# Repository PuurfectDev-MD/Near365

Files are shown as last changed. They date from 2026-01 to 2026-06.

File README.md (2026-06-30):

# Wacky and cute- *self claimed :)* Music Player 

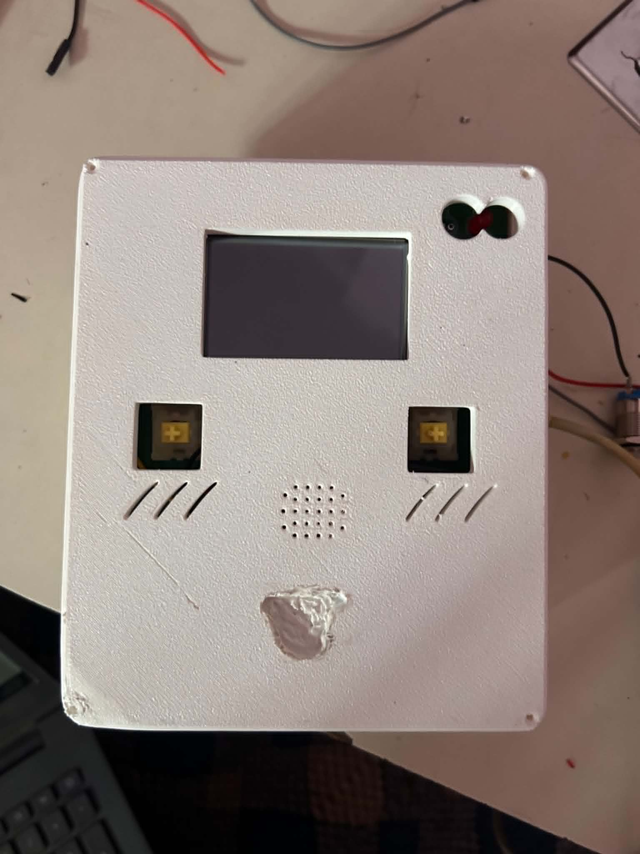
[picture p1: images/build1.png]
Build picture


**Music Player v1** is a interactive  media device (media form: music, voice recording, text, gifs and video possibly) powered by an ESP32-S3.I designed it as a personalized gift,to play unique music, affirmations,  every single day onpre-programmed schedule. v2 will have an APi endpoint to post voice recordings over the internet and other cool features. The device is a complete package for audio related projects and can be modified into other creative ideas like - (voice journal keeper, online music streaming and many more!)

---

## Features

* **Daily Present:** Automatically fetches unique content (music and text(affiramtions/notes)) from an SD card based on the current date.
* **High-quality Audio:** Uses I2S protocol with a MAX98357A DAC for clear, non-blocking WAV file playback.
* **Voice Recorder:** Record and save voice memos directly to the SD card for future playback ** Plans to stream it over the internet
* **Music Player:** Plays music playlists from the sd card
* **Peculiar Cute design** Cute 3d model case enclosure with a tounge sticking out 😛

---

##  Hardware Design

### Schematic
The system integrates an ESP32-S3 with I2S audio, SPI SD card communication, and I2C/SPI display interfacing.

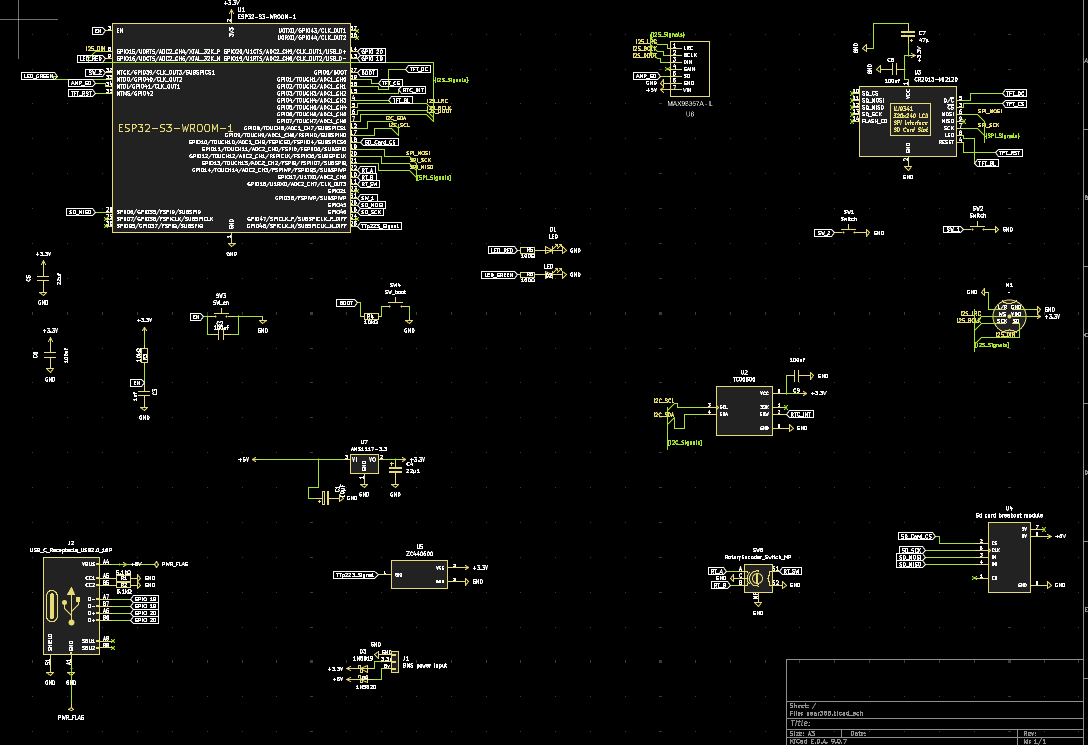
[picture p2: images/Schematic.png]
Schematic

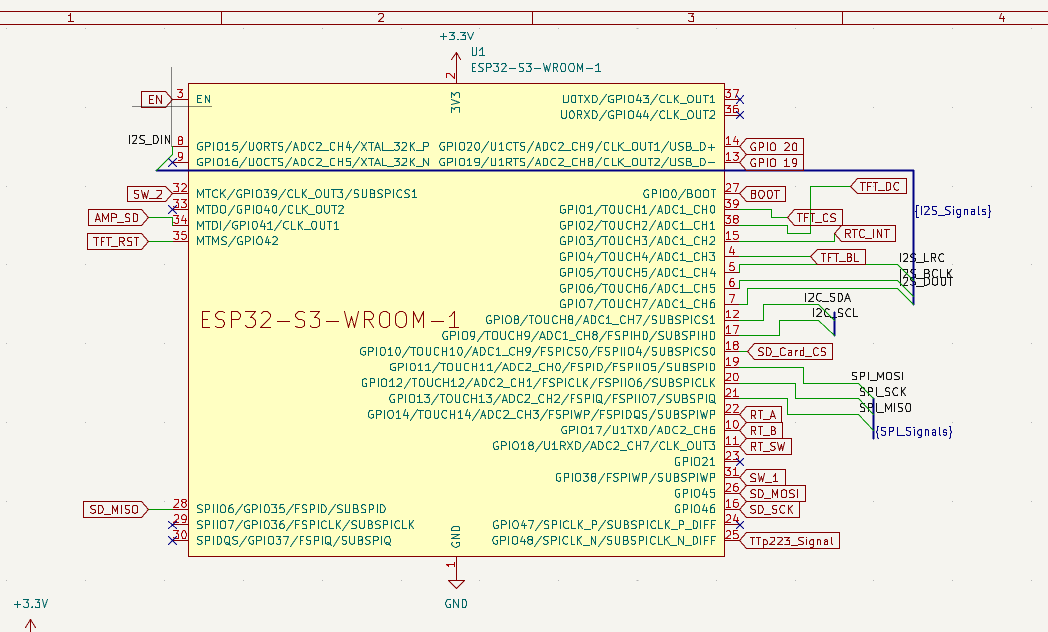
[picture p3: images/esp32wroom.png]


### PCB Design
A custom 2-layer PCB design from kicad.

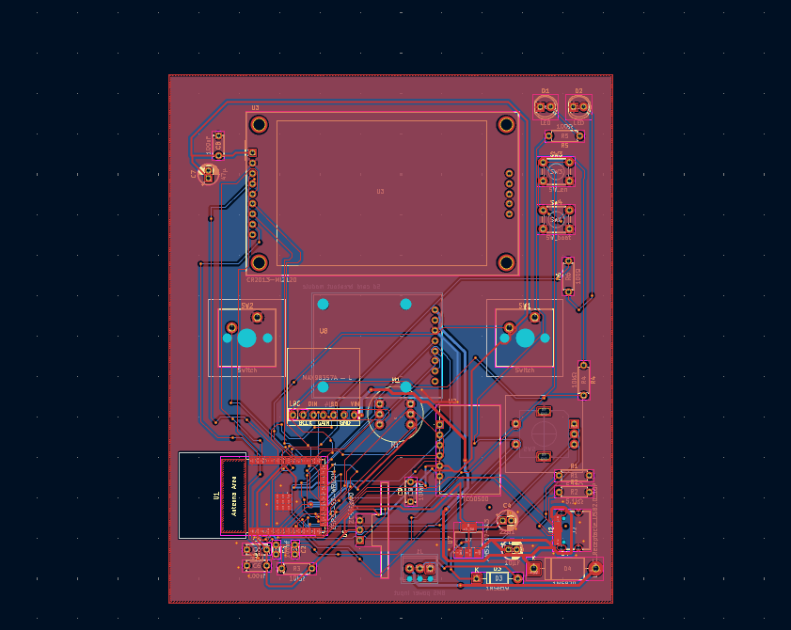
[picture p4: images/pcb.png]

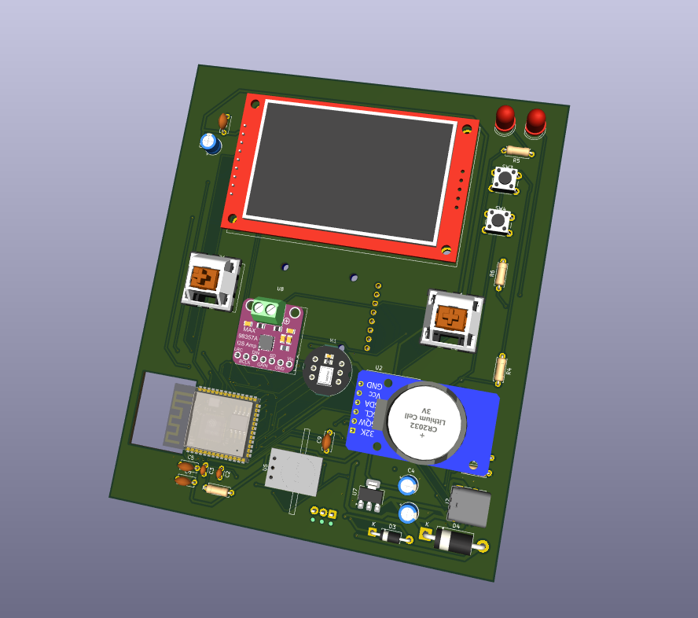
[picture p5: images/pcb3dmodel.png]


### Power Board
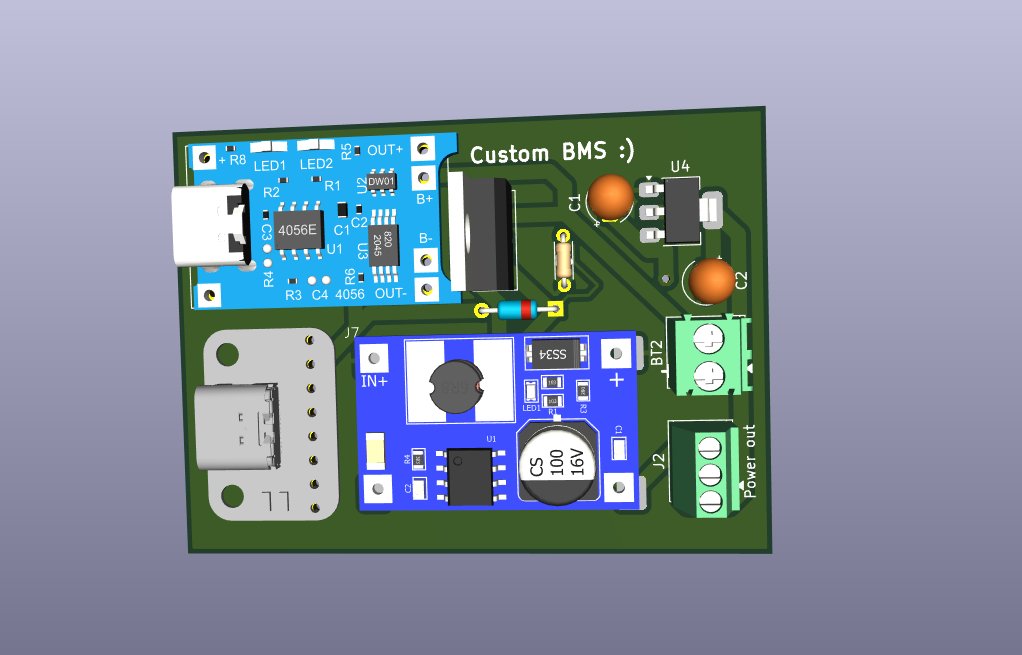
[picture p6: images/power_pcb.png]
Power PCB

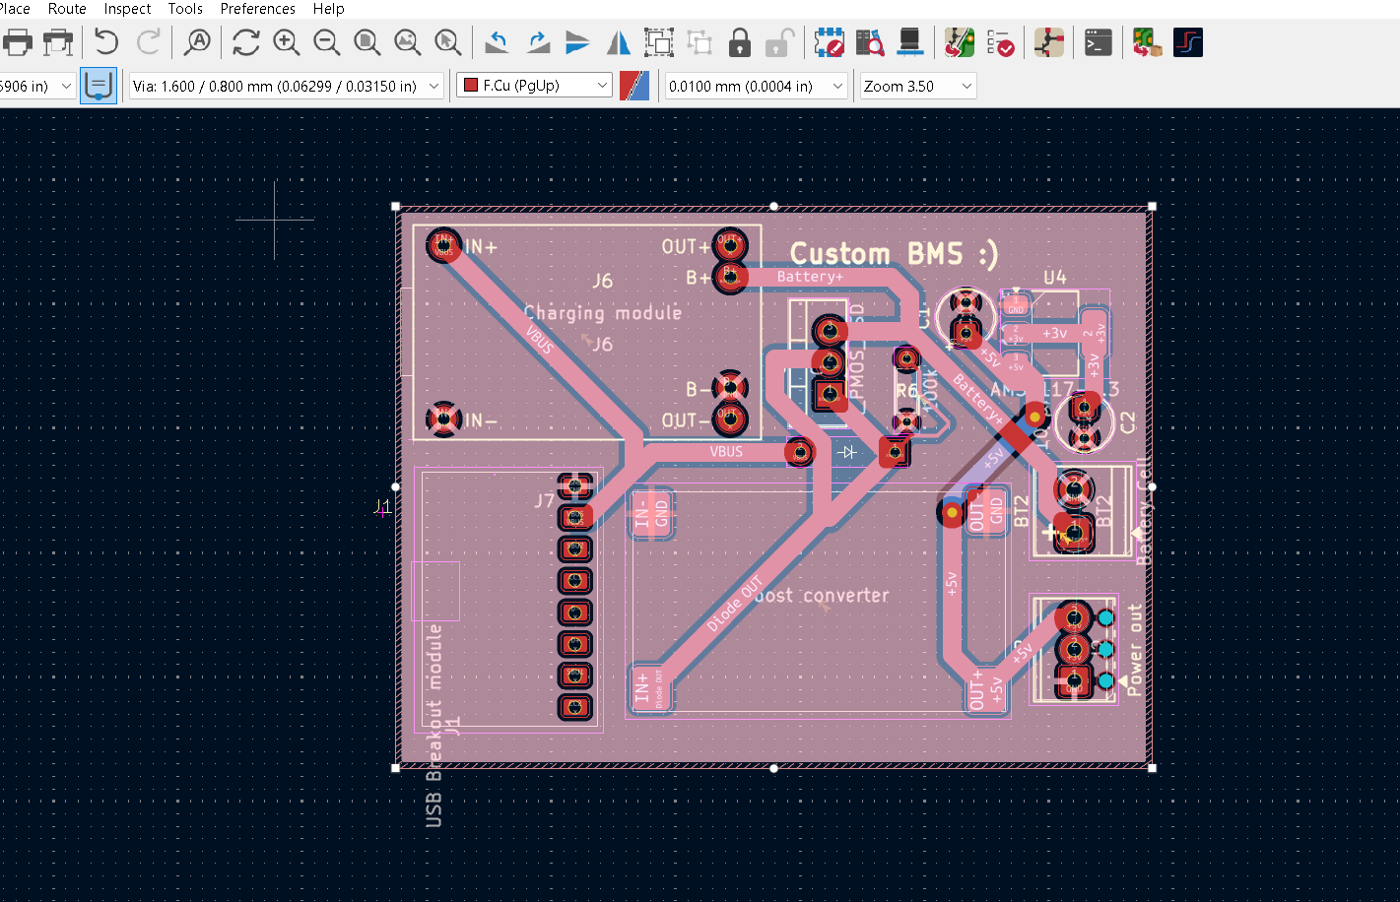
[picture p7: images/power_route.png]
Power traces

### 3D Model for Case
A custom 3d model case from fusion 360

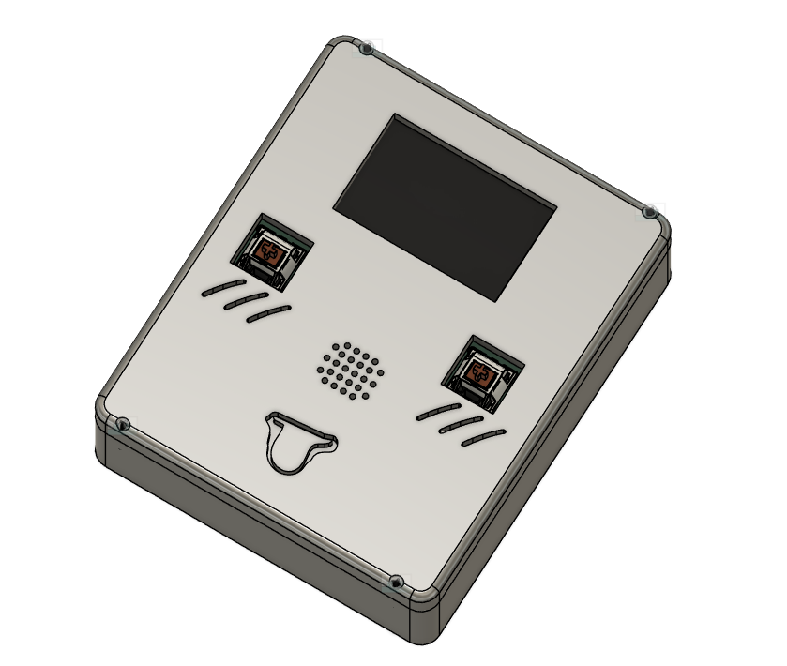
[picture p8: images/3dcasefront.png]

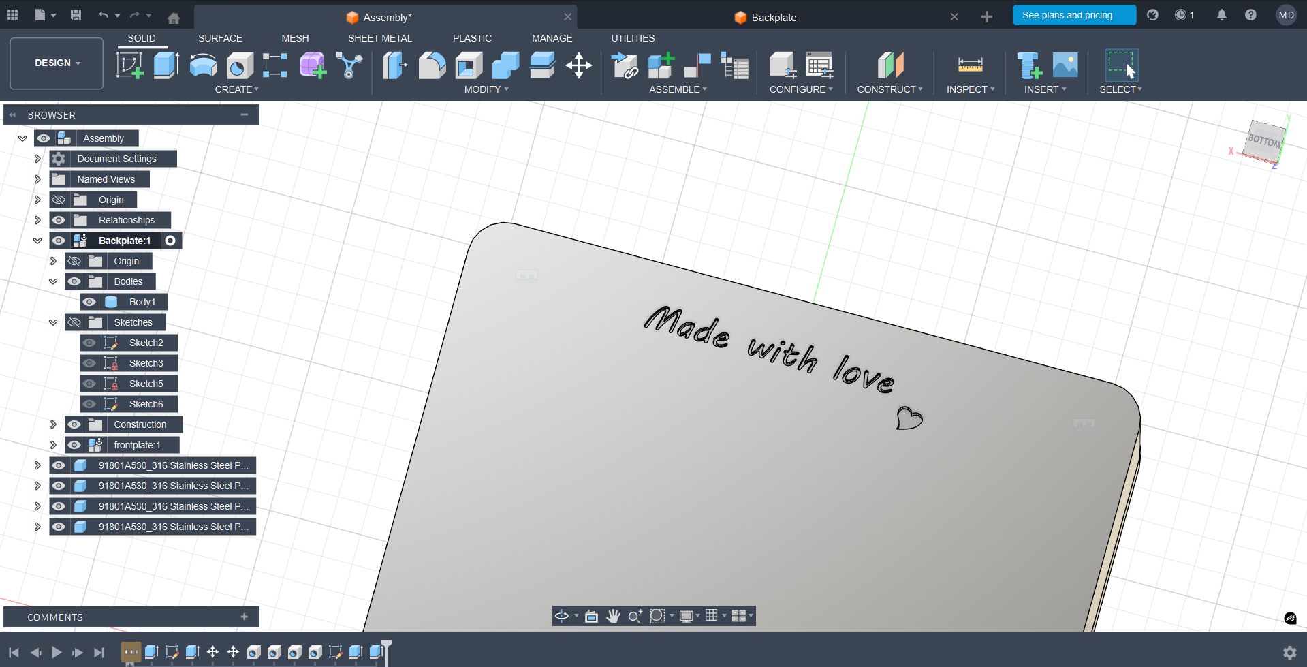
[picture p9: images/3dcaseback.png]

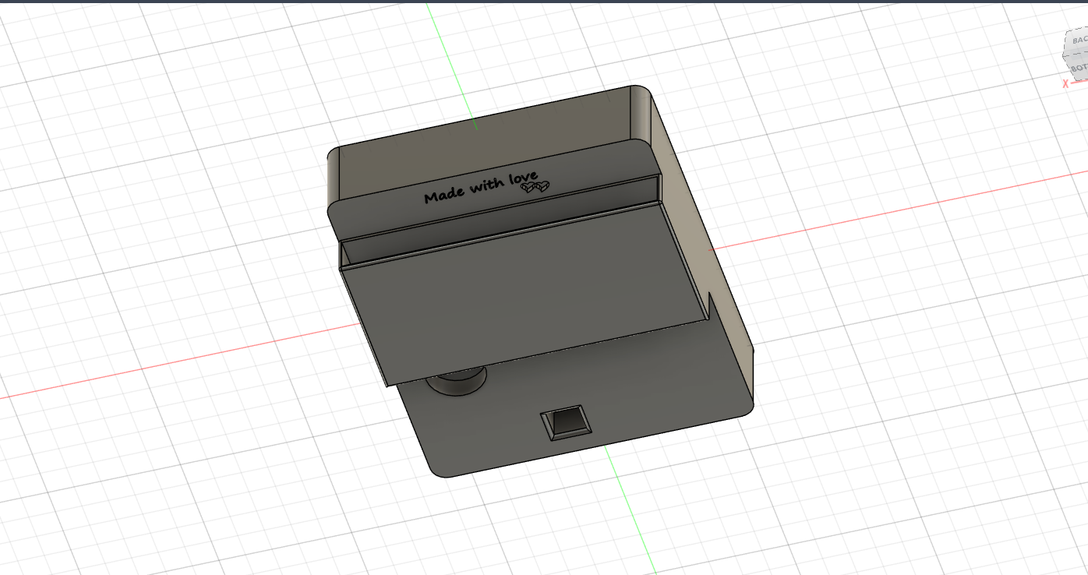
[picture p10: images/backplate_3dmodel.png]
3D Model Render

---
##  Bill of Materials (BOM)

| Component | Description | Quantity |
| :--- | :--- | :--- |
| **Microcontroller** | ESP32-S3 (WROOM-1-N16R8) | 1 |
| **Display** | 2.4" TFT LCD (ILI9341 Driver) | 1 |
| **Audio DAC/Amp** | MAX98357A I2S Class D Amplifier | 1 |
| **Speaker** | 3W 4-Ohm Internal Speaker | 1 |
| **Rotary Encoder** | EC11 Encoder with Push-Button Switch | 1 |
| **Touch Sensor** | TTP223 Capacitive Touch Module (Soft Power)  | 1 |
| **SD card module** | Adafruit Micro SD Card Breakout Board | 1 |
| **Microphone** | INMP441 I2S Digital Omnidirectional Mic | 1 |
| **RTC Module** | DS3231 High-Precision I2C RTC | 1 |
| **Storage Card** | 16GB Micro SD Card | 1 |
| **BMS Board** | Custom made battery management system | 1 |
> [!NOTE]
> This is just a summary of the BOM. The complete BOM can be found in [`/BOM details/project.csv`](BOM%20details/project.csv)
---

##  Project Structure

* `firmware/pages`: Contains the class logic for each UI state (`Daily`, `Music`, `Record`, `History`).
* `main.py`: The primary async loop and state machine handler.
* `setup.py`: Hardware initialization and pin mapping.
* `master.json`: The central database for the daily gift schedule.

## File Structure:

* `/3d Model`: Contains fusion and 3d printing files for the case.
* `/firmware`: Contains the code
* `Kicad`: Kicad files (both power and main board)
       * `Power_kicad`: Custom made bms system kicad project
       * `main_kicad`: main pcb kicad project
* `/images`: For images of README.md
* `/BOM details`: For BOM from Kicad and my cost compiled for the enitre project
          *`project.csv`: For cost compiled BOM
* `Gerber Files`: For JLCPCB or any other manufacturer
          * `production_main`: Gerber for the main pcb
          * `production_power`: Gerber for the BMS pcb

---

# Why build this?
I built it becasue I really wanted to get into making a custom esp32 chip board and happened to stumble upon a music player gift idea. And from there I spiralled into making the best version of my idea. It plays a different song and displays unique affiramtions from a predefined library to bringten up someones day. OFC my handcrafted playlist library is the biggest treasure :). You can build your own too! For yourself or for someone else. Good Luck >> After you complete it, share it with me from the info at https://manishd.is-a.dev/ .

# My build

### What Works Perfectly:
* **Playback:** Successfully fetches scheduled daily gifts/affirmations and plays audio
* **Network & Time Sync:** Connects to the internet to update and synchronize time data via API
* **Custom UI:** The custom LVGL-based TFT user interface turned out beautifully and performs well 

### Improvements that could better my build:
1. **The BMS Architecture:** Looking back, splitting the power/BMS circuit onto a separate board added unnecessary assembly complexity. For v2, the power management circuit will on a singl PCB.
2. **I2S Audio Recording:** While standalone microphone test scripts work flawlessly, fully integrating the voice-recording firmware into the main async package remains a work-in-progress becasue of some pin conflict
3. **Prototyping Materials Matter:** Using standard breadboard jumper wires and low-quality solder wire made internal routing extremely messy and prone to weak joints and gave me a veryvery hard time during building. This also made the final result messy and prone to breaking down/short ciruit.
4. **Hardware Casualty:** During the final hardware assembly stages, the TFT display took some physical damage which was just devestating. But it works kinda alright so fine i guess.

<details>
<summary><b> This is the tft after damage</b></summary>
<br />
<p align="center">
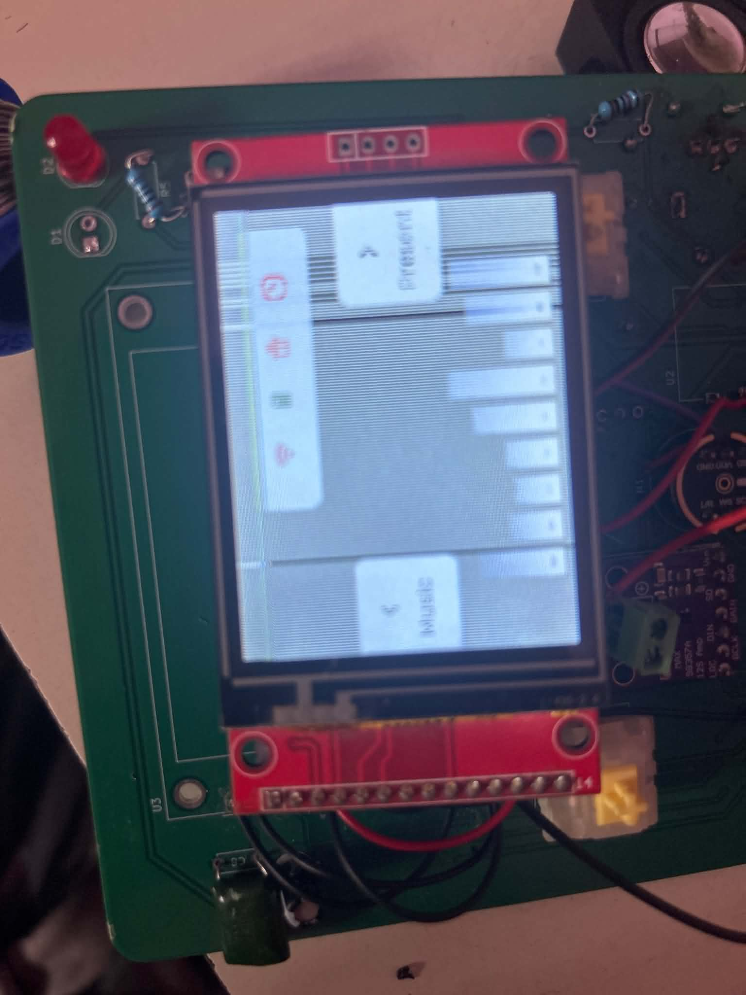
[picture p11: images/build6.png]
Internal Circuitry and Wiring
  
  <br />
  <sub>It works though so its fine guess.</sub>
</p>
</details>

---
> 💡 **Note:** This video was recorded during early testing. Some UI components shown in the gallery below are not visible in the clip. use the static images for final UI reference.

#### From the outside
<table width="100%">
  <tr>
    <td width="50%" align="center">
      Hardware Front View
      <br />
      <sub><b>Enclosure Assembly</b></sub>
    </td>
    <td width="50%" align="center">
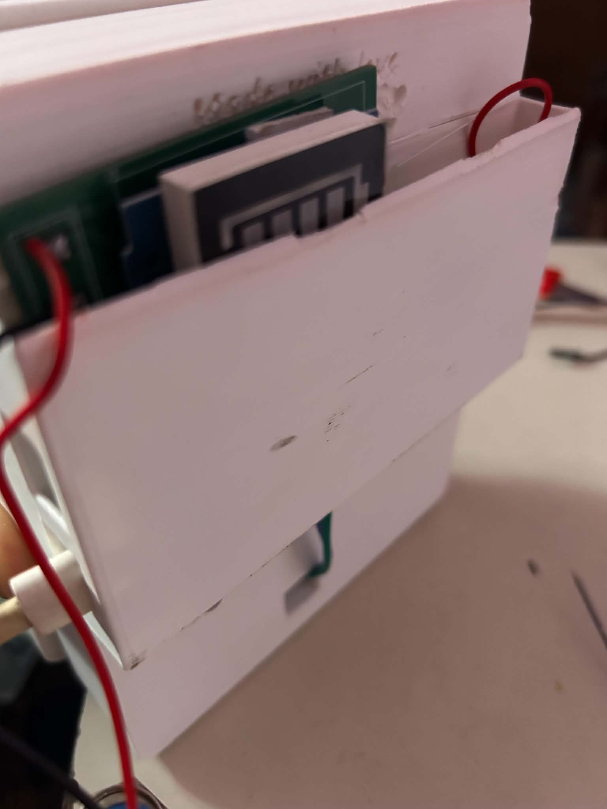
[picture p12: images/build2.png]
Hardware Angled View
      
      <br />
      <sub><b>Wacky Cute Tongue Profile 😛</b></sub>
    </td>
  </tr>
</table>

#### UI
<table width="100%">
  <tr>
    <td width="33%" align="center">
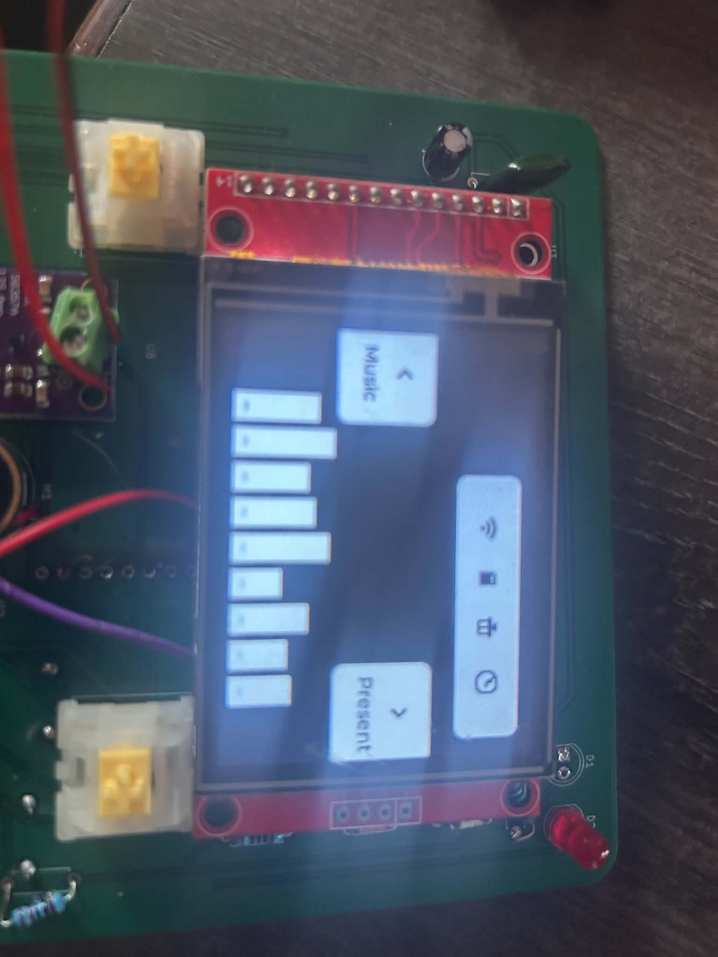
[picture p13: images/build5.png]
UI Screen Boot
      
      <br />
      <sub><b>Home</b></sub>
    </td>
    <td width="33%" align="center">
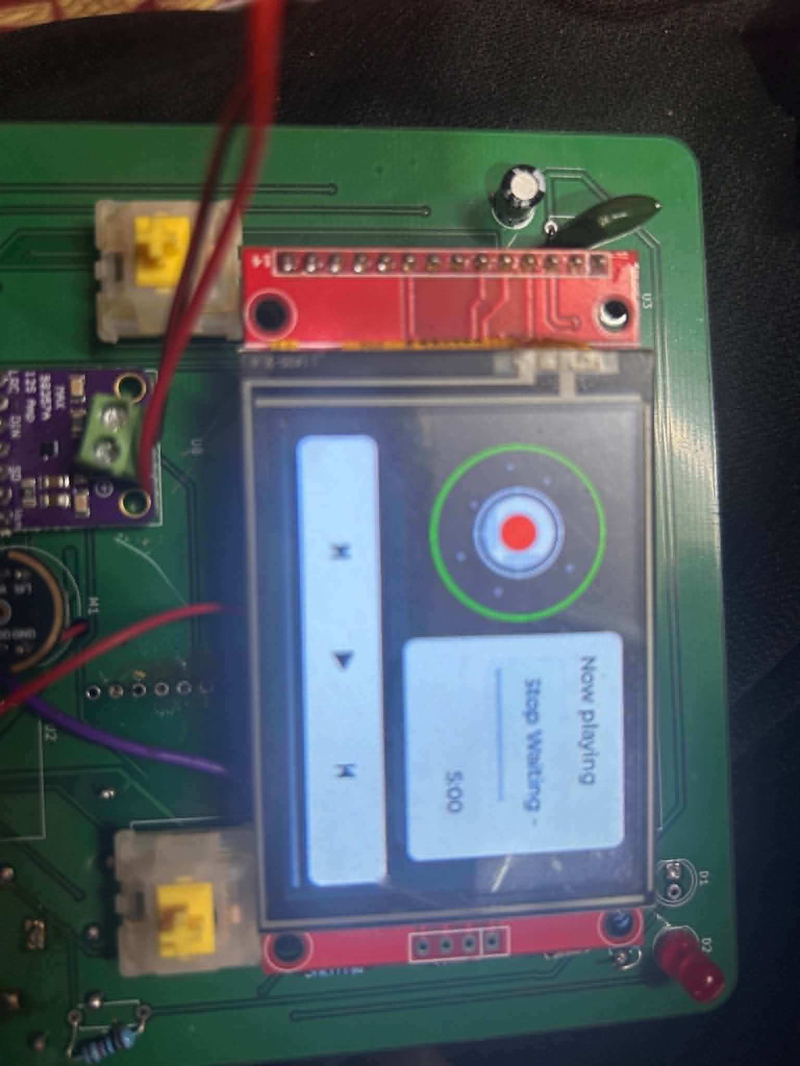
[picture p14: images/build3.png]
UI Menu Layout
      
      <br />
      <sub><b>Music Screen</b></sub>
    </td>
    <td width="33%" align="center">
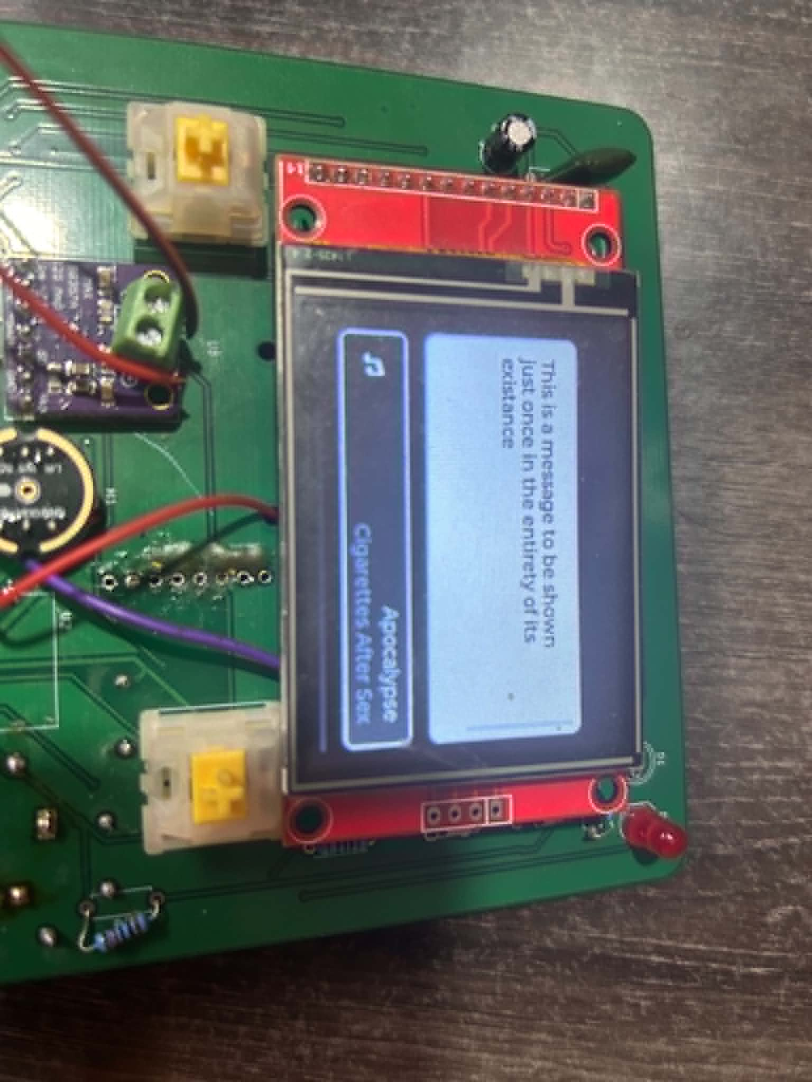
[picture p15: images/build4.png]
Assembled Face
      
      <br />
      <sub><b>Gift screen</b></sub>
    </td>
  </tr>
</table>

## AI USE:
I used AI heavily for the coding part. Around 40%-50%. Majority of the project is hardware based so AI use for the whole project is less than 25%. The things I used AI for - 

- Help with KICAD DRC issue
- Help with hole configuration on Fusion 360
- Troubleshooting design elements
- LVGL library and firmware setup (first time using it so thats why)
- LVGL library functions
- Acurate Encoder Input 

And a lot of debugging stuff.

*Created with love❤️.*

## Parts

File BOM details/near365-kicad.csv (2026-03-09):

Reference | Qty | Value | DNP | Exclude from BOM | Exclude from Board | Footprint | Datasheet
C1 | 1 | 10μF |  |  |  | Capacitor_THT:CP_Radial_D5.0mm_P2.00mm | ~
C2 | 1 | 100nf |  |  |  | Capacitor_THT:C_Disc_D3.0mm_W1.6mm_P2.50mm | ~
C3 | 1 | 1uf |  |  |  | Capacitor_THT:C_Disc_D3.0mm_W1.6mm_P2.50mm | ~
C4 | 1 | 22μ1 |  |  |  | Capacitor_THT:CP_Radial_D5.0mm_P2.00mm | ~
C5 | 1 | 22uf |  |  |  | Capacitor_THT:C_Disc_D5.0mm_W2.5mm_P5.00mm | ~
C6,C8,C9 | 3 | 100nf |  |  |  | Capacitor_THT:C_Disc_D5.0mm_W2.5mm_P5.00mm | ~
C7 | 1 | 47μ |  |  |  | Capacitor_THT:CP_Radial_D5.0mm_P2.00mm | ~
D1,D2 | 2 | LED |  |  |  | LED_THT:LED_D5.0mm | ~
D3 | 1 | 1N5819 |  |  |  | Diode_THT:D_DO-41_SOD81_P10.16mm_Horizontal | http://www.vishay.com/docs/88525/1n5817.pdf
D4 | 1 | 1N5820 |  |  |  | Diode_THT:D_DO-201AD_P15.24mm_Horizontal | http://www.vishay.com/docs/88526/1n5820.pdf
J1 | 1 | BMS power input |  |  |  | TerminalBlock_Phoenix:TerminalBlock_Phoenix_MPT-0,5-3-2.54_1x03_P2.54mm_Horizontal | ~
J2 | 1 | USB_C_Receptacle_USB2.0_16P |  |  |  | Connector_USB:USB_C_Receptacle_HRO_TYPE-C-31-M-12 | https://www.usb.org/sites/default/files/documents/usb_type-c.zip
M1 | 1 | ~ |  |  |  | INMP441_Microphone:INMP441_module
R1,R2 | 2 | 5.1kΩ |  |  |  | Resistor_THT:R_Axial_DIN0207_L6.3mm_D2.5mm_P7.62mm_Horizontal | ~
R3,R4 | 2 | 10kΩ |  |  |  | Resistor_THT:R_Axial_DIN0207_L6.3mm_D2.5mm_P7.62mm_Horizontal | ~
R5,R6 | 2 | 100Ω |  |  |  | Resistor_THT:R_Axial_DIN0207_L6.3mm_D2.5mm_P7.62mm_Horizontal | ~
SW1,SW2 | 2 | Switch |  |  |  | ScottoKeebs_MX:MX_PCB_1.00u | ~
SW3 | 1 | SW_en |  |  |  | Button_Switch_THT:SW_PUSH_6mm | ~
SW4 | 1 | SW_boot |  |  |  | Button_Switch_THT:SW_PUSH_6mm | ~
SW5 | 1 | RotaryEncoder_Switch_MP |  |  |  | ScottoKeebs_Scotto:Encoder_EC11_MX | ~
U1 | 1 | ESP32-S3-WROOM-1 |  |  |  | PCM_Espressif:ESP32-S3-WROOM-1 | https://www.espressif.com/sites/default/files/documentation/esp32-s3-wroom-1_wroom-1u_datasheet_en.pdf
U2 | 1 | TC00500 |  |  |  | Real_TimeClk:MODULE_TC00500
U3 | 1 | CR2013-MI2120 |  |  |  | Display:CR2013-MI2120 | http://pan.baidu.com/s/11Y990
U4 | 1 | Sd card breakout module |  |  |  | Adafruit Sd breakout:MODULE_254
U5 | 1 | ZC440600 |  |  |  | TTP223:MODULE_ZC440600
U7 | 1 | AMS1117-3.3 |  |  |  | Package_TO_SOT_SMD:SOT-223-3_TabPin2 | http://www.advanced-monolithic.com/pdf/ds1117.pdf
U8 | 1 | MAX98357A - L |  |  |  | MAX98357A_custom:MAX98357A_Adafruit_Breakout | https://www.adafruit.com/product/3006

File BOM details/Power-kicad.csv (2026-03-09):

Reference | Qty | Value | DNP | Exclude from BOM | Exclude from Board | Footprint | Datasheet
BT2 | 1 | Battery_Cell |  |  |  | TerminalBlock_Phoenix:TerminalBlock_Phoenix_PT-1,5-2-3.5-H_1x02_P3.50mm_Horizontal | ~
C1,C2 | 2 | 10 µF |  |  |  | Capacitor_THT:CP_Radial_Tantal_D4.5mm_P2.50mm | ~
D2 | 1 | ~ |  |  |  | ScottoKeebs_Components:Diode_DO-35
J1 | 1 | USB Breakout module |  |  |  | USB Breakout board:Usb_breakout board | ~
J2 | 1 | Power out |  |  |  | TerminalBlock_Phoenix:TerminalBlock_Phoenix_MPT-0,5-3-2.54_1x03_P2.54mm_Horizontal | ~
J6 | 1 | Charging module |  |  |  | Charging module:TP4056-Module | ~
J7 | 1 | Boost converter |  |  |  | Boost_converter_module:Boost_converter_3A | ~
Q2 | 1 | Q_PMOS_GSD |  |  |  | Package_TO_SOT_THT:TO-220-3_Vertical | ~
R6 | 1 | 100k |  |  |  | Resistor_THT:R_Axial_DIN0204_L3.6mm_D1.6mm_P5.08mm_Horizontal | ~
U4 | 1 | AMS1117-3.3 |  |  |  | Package_TO_SOT_SMD:SOT-223-3_TabPin2 | http://www.advanced-monolithic.com/pdf/ds1117.pdf

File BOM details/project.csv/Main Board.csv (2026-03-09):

Reference | Qty | Value | Footprint | Price | Datasheet
C1 | 1 | 10μF | Capacitor_THT:CP_Radial_D5.0mm_P2.00mm | $0.35 | ~
C2 | 1 | 100nf | Capacitor_THT:C_Disc_D3.0mm_W1.6mm_P2.50mm | $0.35 | ~
C3 | 1 | 1uf | Capacitor_THT:C_Disc_D3.0mm_W1.6mm_P2.50mm | $0.35 | ~
C4 | 1 | 22μ1 | Capacitor_THT:CP_Radial_D5.0mm_P2.00mm | $0.35 | ~
C5 | 1 | 22uf | Capacitor_THT:C_Disc_D5.0mm_W2.5mm_P5.00mm | $0.35 | ~
C6,C8,C9 | 3 | 100nf | Capacitor_THT:C_Disc_D5.0mm_W2.5mm_P5.00mm | $0.35 | ~
C7 | 1 | 47μ | Capacitor_THT:CP_Radial_D5.0mm_P2.00mm | $0.35 | ~
%s12.00 | 2 | LED | LED_THT:LED_D5.0mm | $0.20 | ~
D3 | 1 | 1N5819 | Diode_THT:D_DO-41_SOD81_P10.16mm_Horizontal | $1 | http://www.vishay.com/docs/88525/1n5817.pdf
D4 | 1 | 1N5820 | Diode_THT:D_DO-201AD_P15.24mm_Horizontal | $2 | http://www.vishay.com/docs/88526/1n5820.pdf
J1 | 1 | BMS power input | TerminalBlock_Phoenix:TerminalBlock_Phoenix_MPT-0,5-3-2.54_1x03_P2.54mm_Horizontal | $1 | ~
J2 | 1 | USB_C_Receptacle_USB2.0_16P | Connector_USB:USB_C_Receptacle_HRO_TYPE-C-31-M-12 | $3 | https://www.usb.org/sites/default/files/documents/usb_type-c.zip
M1 | 1 | ~ | INMP441_Microphone:INMP441_module | $3
%s12.00 | 2 | 5.1kΩ | Resistor_THT:R_Axial_DIN0207_L6.3mm_D2.5mm_P7.62mm_Horizontal | $0.10 | ~
%s34.00 | 2 | 10kΩ | Resistor_THT:R_Axial_DIN0207_L6.3mm_D2.5mm_P7.62mm_Horizontal | $0.10 | ~
%s56.00 | 2 | 100Ω | Resistor_THT:R_Axial_DIN0207_L6.3mm_D2.5mm_P7.62mm_Horizontal | $0.10 | ~
SW1,SW2 | 2 | Switch | ScottoKeebs_MX:MX_PCB_1.00u | $2 | ~
SW3 | 1 | SW_en | Button_Switch_THT:SW_PUSH_6mm | $0.50 | ~
SW4 | 1 | SW_boot | Button_Switch_THT:SW_PUSH_6mm | $0.50 | ~
SW5 | 1 | RotaryEncoder_Switch_MP | ScottoKeebs_Scotto:Encoder_EC11_MX | $3 | ~
U1 | 1 | ESP32-S3-WROOM-1 | PCM_Espressif:ESP32-S3-WROOM-1 | $4 | https://www.espressif.com/sites/default/files/documentation/esp32-s3-wroom-1_wroom-1u_datasheet_en.pdf
U2 | 1 | TC00500 | Real_TimeClk:MODULE_TC00500 | $2
U3 | 1 | TFT display | Display:CR2013-MI2120 | $8.23 | http://pan.baidu.com/s/11Y990
U4 | 1 | Sd card breakout module | Adafruit Sd breakout:MODULE_254 | $10
U5 | 1 | ZC440600 | TTP223:MODULE_ZC440600 | $0.50
U7 | 1 | AMS1117-3.3 | Package_TO_SOT_SMD:SOT-223-3_TabPin2 | $1 | http://www.advanced-monolithic.com/pdf/ds1117.pdf
U8 | 1 | MAX98357A - L | MAX98357A_custom:MAX98357A_Adafruit_Breakout | $2 | https://www.adafruit.com/product/3006
 | 1 | SD Card- 8GB |  | $5
 |  |  | Total: | $50.68

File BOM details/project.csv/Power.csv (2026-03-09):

Reference | Qty | Value | Price | Footprint
BT2 | 1 | Battery_Cell | $6 | TerminalBlock_Phoenix:TerminalBlock_Phoenix_PT-1,5-2-3.5-H_1x02_P3.50mm_Horizontal
C1,C2 | 2 | 10 µF | $0.20 | Capacitor_THT:CP_Radial_Tantal_D4.5mm_P2.50mm
D2 | 1 | ~ | $0.50 | ScottoKeebs_Components:Diode_DO-35
J1 | 1 | USB Breakout module | $1 | USB Breakout board:Usb_breakout board
J2 | 1 | Power out | $1.26 | TerminalBlock_Phoenix:TerminalBlock_Phoenix_MPT-0,5-3-2.54_1x03_P2.54mm_Horizontal
J6 | 1 | Charging module | $1.50 | Charging module:TP4056-Module
J7 | 1 | Boost converter | $3.50 | Boost_converter_module:Boost_converter_3A
Q2 | 1 | Q_PMOS_GSD | $1 | Package_TO_SOT_THT:TO-220-3_Vertical
R6 | 1 | 100k | $0.10 | Resistor_THT:R_Axial_DIN0204_L3.6mm_D1.6mm_P5.08mm_Horizontal
U4 | 1 | AMS1117-3.3 | $1 | Package_TO_SOT_SMD:SOT-223-3_TabPin2
 |  | Total: | $16

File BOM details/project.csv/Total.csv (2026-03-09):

Item | Price | Shipping | Total
Main Board | $50.68 | $10
Power Board | $16
Soldering Flux paste | $2.50
M2 * 16mm Screws | $1.62
PCB Cost for Main Board | $10
PCB Cost for Power Board | $2 | $15
3d printing costs for the case | $25 | $15
 | Total: $110 | $40
 | Final Total: | $150

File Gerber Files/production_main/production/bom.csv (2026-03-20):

Designator | Footprint | Quantity | Value | LCSC Part #
C1 | CP_Radial_D5.0mm_P2.00mm | 1 | 10μF
C2 | C_Disc_D3.0mm_W1.6mm_P2.50mm | 1 | 100nf
C3 | C_Disc_D3.0mm_W1.6mm_P2.50mm | 1 | 1uf
C4 | CP_Radial_D5.0mm_P2.00mm | 1 | 22μ1
C5 | C_Disc_D5.0mm_W2.5mm_P5.00mm | 1 | 22uf
C6, C8, C9 | C_Disc_D5.0mm_W2.5mm_P5.00mm | 3 | 100nf
C7 | CP_Radial_D5.0mm_P2.00mm | 1 | 47μ
D1, D2 | LED_D5.0mm | 2 | LED
D3 | D_DO-41_SOD81_P10.16mm_Horizontal | 1 | 1N5819
D4 | D_DO-201AD_P15.24mm_Horizontal | 1 | 1N5820
J1 | TerminalBlock_Phoenix_MPT-0,5-3-2.54_1x03_P2.54mm_Horizontal | 1 | BMS power input
J2 | USB_C_Receptacle_HRO_TYPE-C-31-M-12 | 1 | USB_C_Receptacle_USB2.0_16P
M1 | INMP441_module | 1 | ~
R1, R2 | R_Axial_DIN0207_L6.3mm_D2.5mm_P7.62mm_Horizontal | 2 | 5.1kΩ
R3, R4, R7, R8, R9 | R_Axial_DIN0207_L6.3mm_D2.5mm_P7.62mm_Horizontal | 5 | 10kΩ
R5, R6 | R_Axial_DIN0207_L6.3mm_D2.5mm_P7.62mm_Horizontal | 2 | 100Ω
SW1, SW2 | MX_PCB_1.00u | 2 | Switch
SW3 | SW_PUSH_6mm | 1 | SW_en
SW4 | SW_PUSH_6mm | 1 | SW_boot
SW5 | Encoder_EC11_MX | 1 | RotaryEncoder_Switch_MP
U1 | ESP32-S3-WROOM-1 | 1 | ESP32-S3-WROOM-1
U2 | MODULE_TC00500 | 1 | TC00500
U3 | CR2013-MI2120 | 1 | CR2013-MI2120
U4 | MODULE_254 | 1 | Sd card breakout module
U5 | MODULE_ZC440600 | 1 | ZC440600
U7 | SOT-223-3_TabPin2 | 1 | AMS1117-3.3
U8 | MAX98357A_Adafruit_Breakout | 1 | MAX98357A - L

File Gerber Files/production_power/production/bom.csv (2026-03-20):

Designator | Footprint | Quantity | Value | LCSC Part #
BT2 | TerminalBlock_Phoenix_PT-1,5-2-3.5-H_1x02_P3.50mm_Horizontal | 1 | Battery_Cell
C1, C2 | CP_Radial_Tantal_D4.5mm_P2.50mm | 2 | 10 µF
D2 | Diode_DO-35 | 1 | ~
J1 | Usb_breakout board | 1 | USB Breakout module
J2 | TerminalBlock_Phoenix_MPT-0,5-3-2.54_1x03_P2.54mm_Horizontal | 1 | Power out
J3 | charge_display | 1 | Charge display
J6 | TP4056-Module | 1 | Charging module
J7 | Boost_converter_3A | 1 | Boost converter
Q2 | TO-220-3_Vertical | 1 | Q_PMOS_GSD
R6 | R_Axial_DIN0204_L3.6mm_D1.6mm_P5.08mm_Horizontal | 1 | 100k
SW1 | Switch_pads | 1 | SW_Push
U4 | SOT-223-3_TabPin2 | 1 | AMS1117-3.3

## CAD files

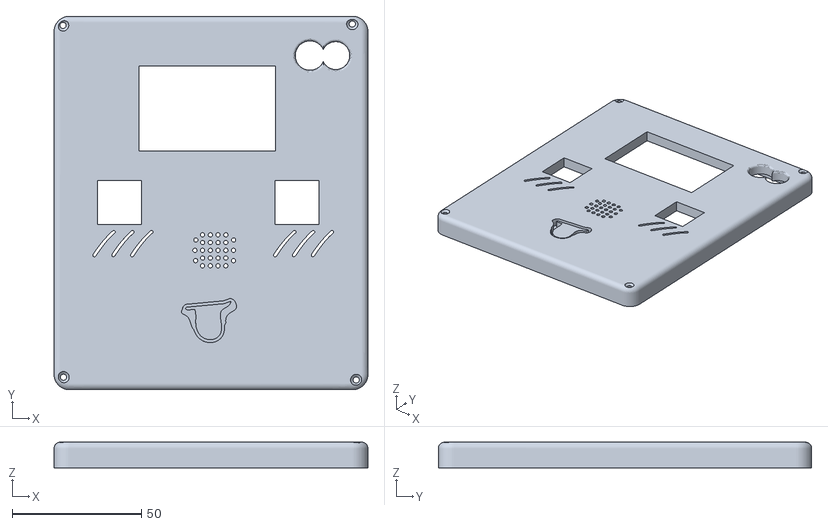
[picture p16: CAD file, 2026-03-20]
3d Model/fusion360/.stl for printing/frontplate.stl
121.6 x 144.7 x 10.0

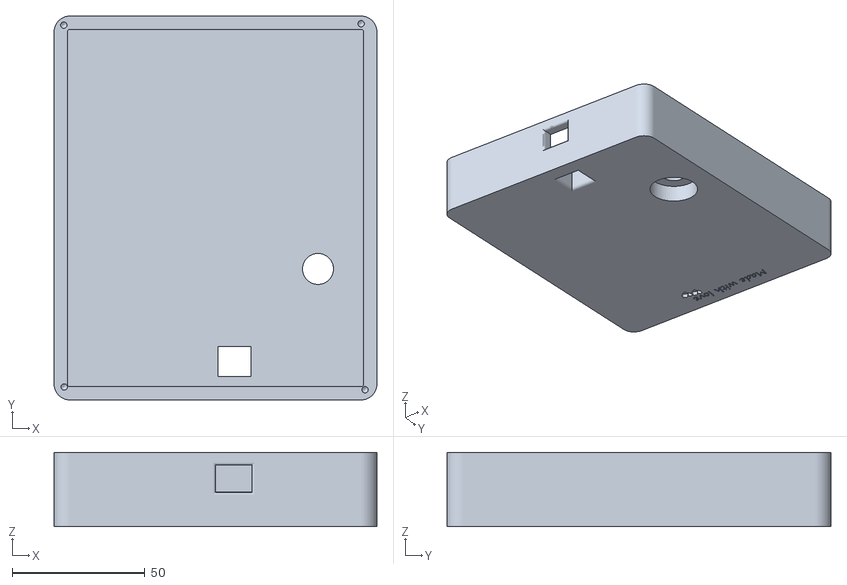
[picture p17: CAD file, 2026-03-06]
3d Model/fusion360/.stl for printing/backplate.stl
121.6 x 144.7 x 28.0

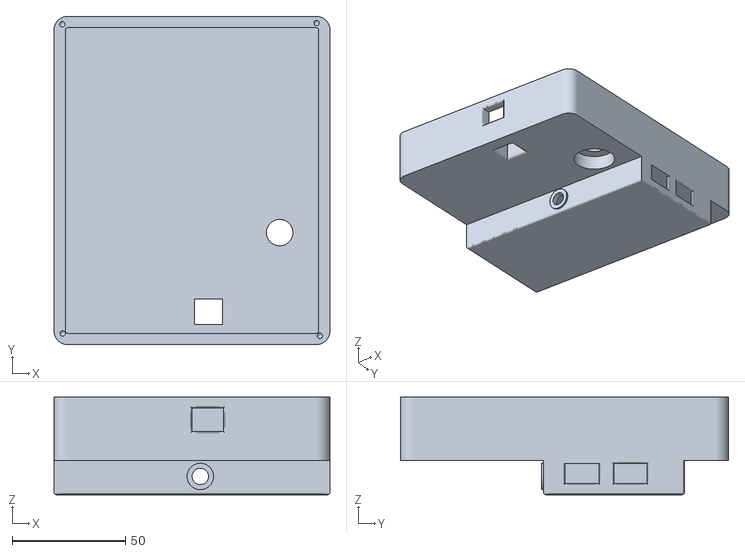
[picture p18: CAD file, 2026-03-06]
3d Model/fusion360/.stl for printing/backplate_redesign.stl
121.6 x 144.7 x 43.0

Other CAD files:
3d Model/fusion360/frontplate.f3z

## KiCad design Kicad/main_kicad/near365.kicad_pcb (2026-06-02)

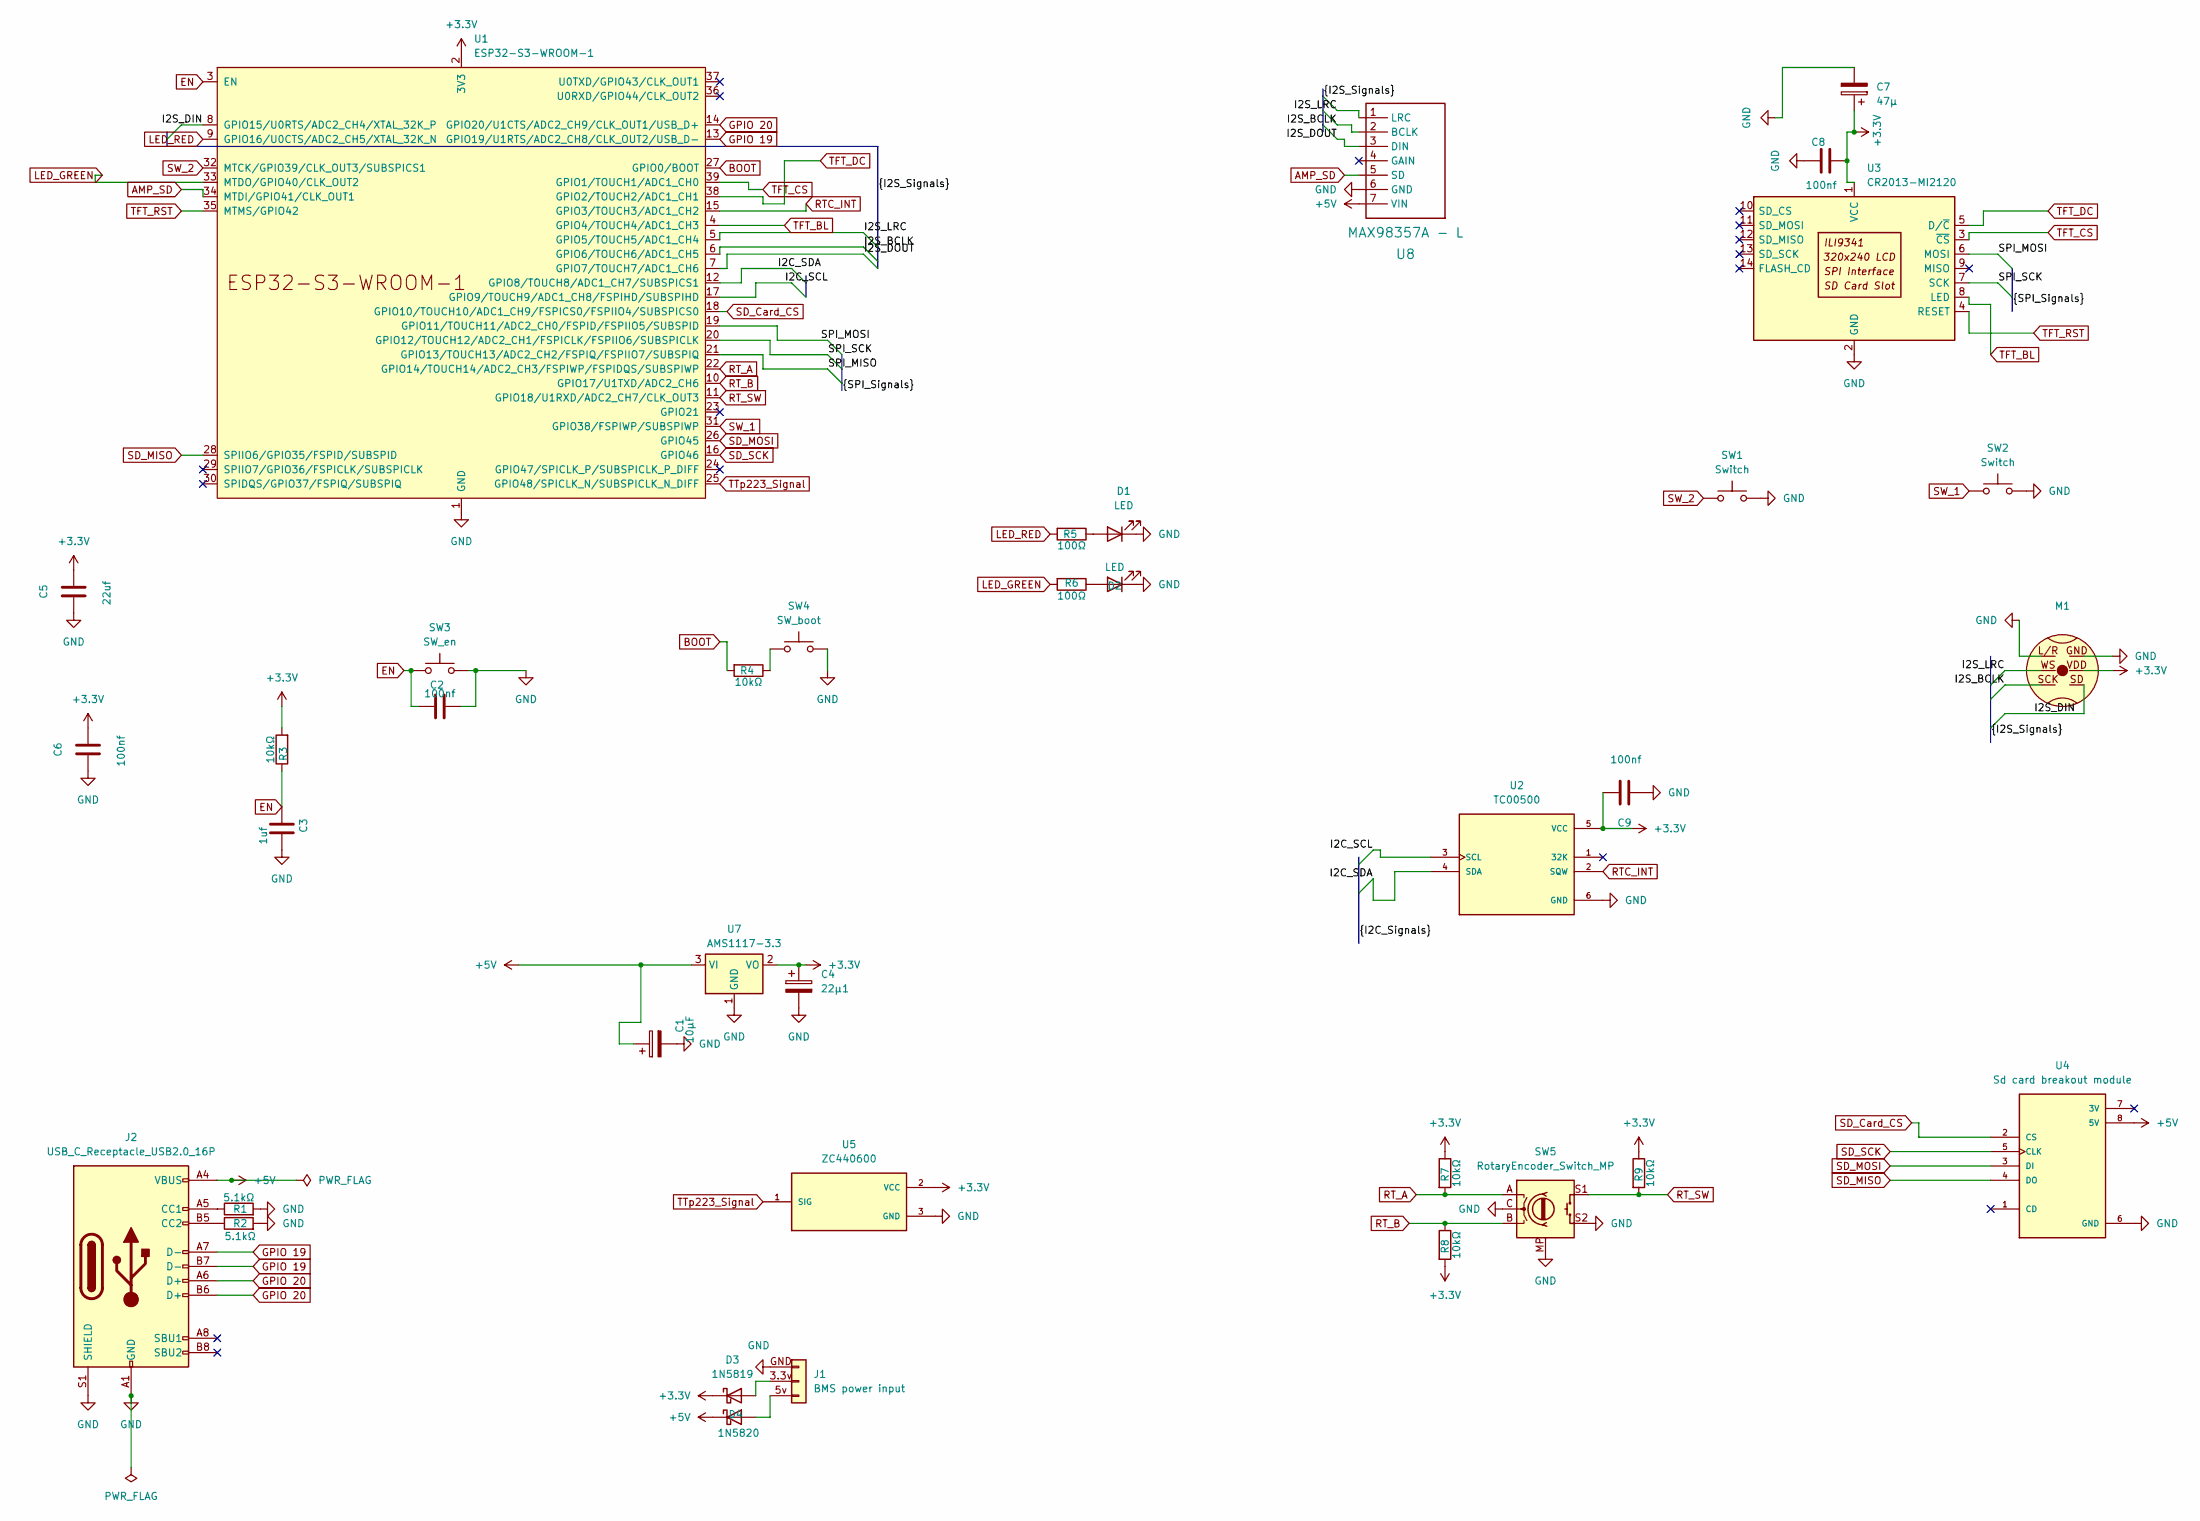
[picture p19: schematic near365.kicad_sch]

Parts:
C1: 10μF; CP_Radial_D5.0mm_P2.00mm
C2: 100nf; C_Disc_D3.0mm_W1.6mm_P2.50mm
C3: 1uf; C_Disc_D3.0mm_W1.6mm_P2.50mm
C4: 22μ1; CP_Radial_D5.0mm_P2.00mm
C5: 22uf; C_Disc_D5.0mm_W2.5mm_P5.00mm
C6, C8, C9: 100nf; C_Disc_D5.0mm_W2.5mm_P5.00mm
C7: 47μ; CP_Radial_D5.0mm_P2.00mm
D1, D2: LED; LED_D5.0mm
D3: 1N5819; D_DO-41_SOD81_P10.16mm_Horizontal
D4: 1N5820; D_DO-201AD_P15.24mm_Horizontal
J1: BMS power input; TerminalBlock_Phoenix_MPT-0,5-3-2.54_1x03_P2.54mm_Horizontal
J2: USB_C_Receptacle_USB2.0_16P; USB_C_Receptacle_HRO_TYPE-C-31-M-12
M1: INMP441_module
R1, R2: 5.1kΩ; R_Axial_DIN0207_L6.3mm_D2.5mm_P7.62mm_Horizontal
R3, R4, R7, R8, R9: 10kΩ; R_Axial_DIN0207_L6.3mm_D2.5mm_P7.62mm_Horizontal
R5, R6: 100Ω; R_Axial_DIN0207_L6.3mm_D2.5mm_P7.62mm_Horizontal
SW1, SW2: Switch; MX_PCB_1.00u
SW3: SW_en; SW_PUSH_6mm
SW4: SW_boot; SW_PUSH_6mm
SW5: RotaryEncoder_Switch_MP; Encoder_EC11_MX
U1: ESP32-S3-WROOM-1
U2: TC00500; MODULE_TC00500; PARTREV N/A
U3: CR2013-MI2120
U4: Sd card breakout module; MODULE_254; PARTREV Jul 31, 2013
U5: ZC440600; MODULE_ZC440600; PARTREV N/A
U7: AMS1117-3.3; SOT-223-3_TabPin2
U8: MAX98357A - L; MAX98357A_Adafruit_Breakout; Manufacturer Part 3006

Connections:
+3.3V: C4.1, C5.2, C6.2, C7.1, C8.2, C9.2, D3.1 (K), M1.VDD, R3.2, R7.1, R8.2, R9.1, U1.2 (3V3), U2.5 (VCC), U3.1 (VCC), U5.2 (VCC), U7.2 (VO)
+5V: C1.1, D4.1 (K), J2.A4 (VBUS), J2.A9 (VBUS), J2.B4 (VBUS), J2.B9 (VBUS), U4.8 (5V), U7.3 (VI), U8.7 (VIN)
/I2C_SCL: U1.17 (GPIO9/TOUCH9/ADC1_CH8/FSPIHD/SUBSPIHD), U2.3 (SCL)
/I2C_SDA: U1.12 (GPIO8/TOUCH8/ADC1_CH7/SUBSPICS1), U2.4 (SDA)
/I2S_BCLK: M1.SCK, U1.6 (GPIO6/TOUCH6/ADC1_CH5), U8.2 (BCLK)
/I2S_DIN: M1.SD, U1.8 (GPIO15/U0RTS/ADC2_CH4/XTAL_32K_P)
/I2S_DOUT: U1.7 (GPIO7/TOUCH7/ADC1_CH6), U8.3 (DIN)
/I2S_LRC: M1.WS, U1.5 (GPIO5/TOUCH5/ADC1_CH4), U8.1 (LRC)
/SPI_MISO: U1.21 (GPIO13/TOUCH13/ADC2_CH2/FSPIQ/FSPIIO7/S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)
/SPI_MOSI: U1.19 (GPIO11/TOUCH11/ADC2_CH0/FSPID/FSPIIO5/S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), U3.6 (MOSI)
/SPI_SCK: U1.20 (GPIO12/TOUCH12/ADC2_CH1/FSPICLK/FSPIIO6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), U3.7 (SCK)
AMP_SD: U1.34 (MTDI/GPIO41/CLK_OUT1), U8.5 (SD)
BOOT: R4.2, U1.27 (GPIO0/BOOT)
EN: C2.1, C3.1, R3.1, SW3.1, U1.3 (EN)
GND: C1.2, C2.2, C3.2, C4.2, C5.1, C6.1, C7.2, C8.1, C9.1, D1.1 (K), D2.1 (K), J1.GND, J2.A1 (GND), J2.A12 (GND), J2.B1 (GND), J2.B12 (GND), J2.S1 (SHIELD), M1.GND, M1.L/R, R1.2, R2.2, SW1.2, SW2.2, SW3.2, SW4.2, SW5.C, SW5.MP, SW5.S2, U1.1 (GND), U1.40 (GND), U1.41 (GND), U2.6 (GND), U3.2 (GND), U4.6 (GND), U5.3 (GND), U7.1 (GND), U8.6 (GND)
GPIO 19: J2.A7 (D-), J2.B7 (D-), U1.13 (GPIO19/U1RTS/ADC2_CH8/CLK_OUT2/USB_D-)
GPIO 20: J2.A6 (D+), J2.B6 (D+), U1.14 (GPIO20/U1CTS/ADC2_CH9/CLK_OUT1/USB_D+)
LED_GREEN: R6.2, U1.33 (MTDO/GPIO40/CLK_OUT2)
LED_RED: R5.2, U1.9 (GPIO16/U0CTS/ADC2_CH5/XTAL_32K_N)
unnamed: D1.2 (A), R5.1
unnamed: D2.2 (A), R6.1
unnamed: D3.2 (A), J1.3.3v
unnamed: D4.2 (A), J1.5v
unnamed: J2.A5 (CC1), R1.1
unnamed: J2.B5 (CC2), R2.1
unnamed: R4.1, SW4.1
RTC_INT: U1.15 (GPIO3/TOUCH3/ADC1_CH2), U2.2 (SQW)
RT_A: R7.2, SW5.A, U1.22 (GPIO14/TOUCH14/ADC2_CH3/FSPIWP/FSPIDQS/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)
RT_B: R8.1, SW5.B, U1.10 (GPIO17/U1TXD/ADC2_CH6)
RT_SW: R9.2, SW5.S1, U1.11 (GPIO18/U1RXD/ADC2_CH7/CLK_OUT3)
SD_Card_CS: U1.18 (GPIO10/TOUCH10/ADC1_CH9/FSPICS0/FSPIIO4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), U4.2 (CS)
SD_MISO: U1.28 (SPIIO6/GPIO35/FSPID/SUBSPID), U4.4 (DO)
SD_MOSI: U1.26 (GPIO45), U4.3 (DI)
SD_SCK: U1.16 (GPIO46), U4.5 (CLK)
SW_1: SW2.1, U1.31 (GPIO38/FSPIWP/SUBSPIWP)
SW_2: SW1.1, U1.32 (MTCK/GPIO39/CLK_OUT3/SUBSPICS1)
TFT_BL: U1.4 (GPIO4/TOUCH4/ADC1_CH3), U3.8 (LED)
TFT_CS: U1.39 (GPIO1/TOUCH1/ADC1_CH0), U3.3 (~CS)
TFT_DC: U1.38 (GPIO2/TOUCH2/ADC1_CH1), U3.5 (D/~C)
TFT_RST: U1.35 (MTMS/GPIO42), U3.4 (RESET)
TTp223_Signal: U1.25 (GPIO48/SPICLK_N/SUBSPICLK_N_DIFF), U5.1 (SIG)

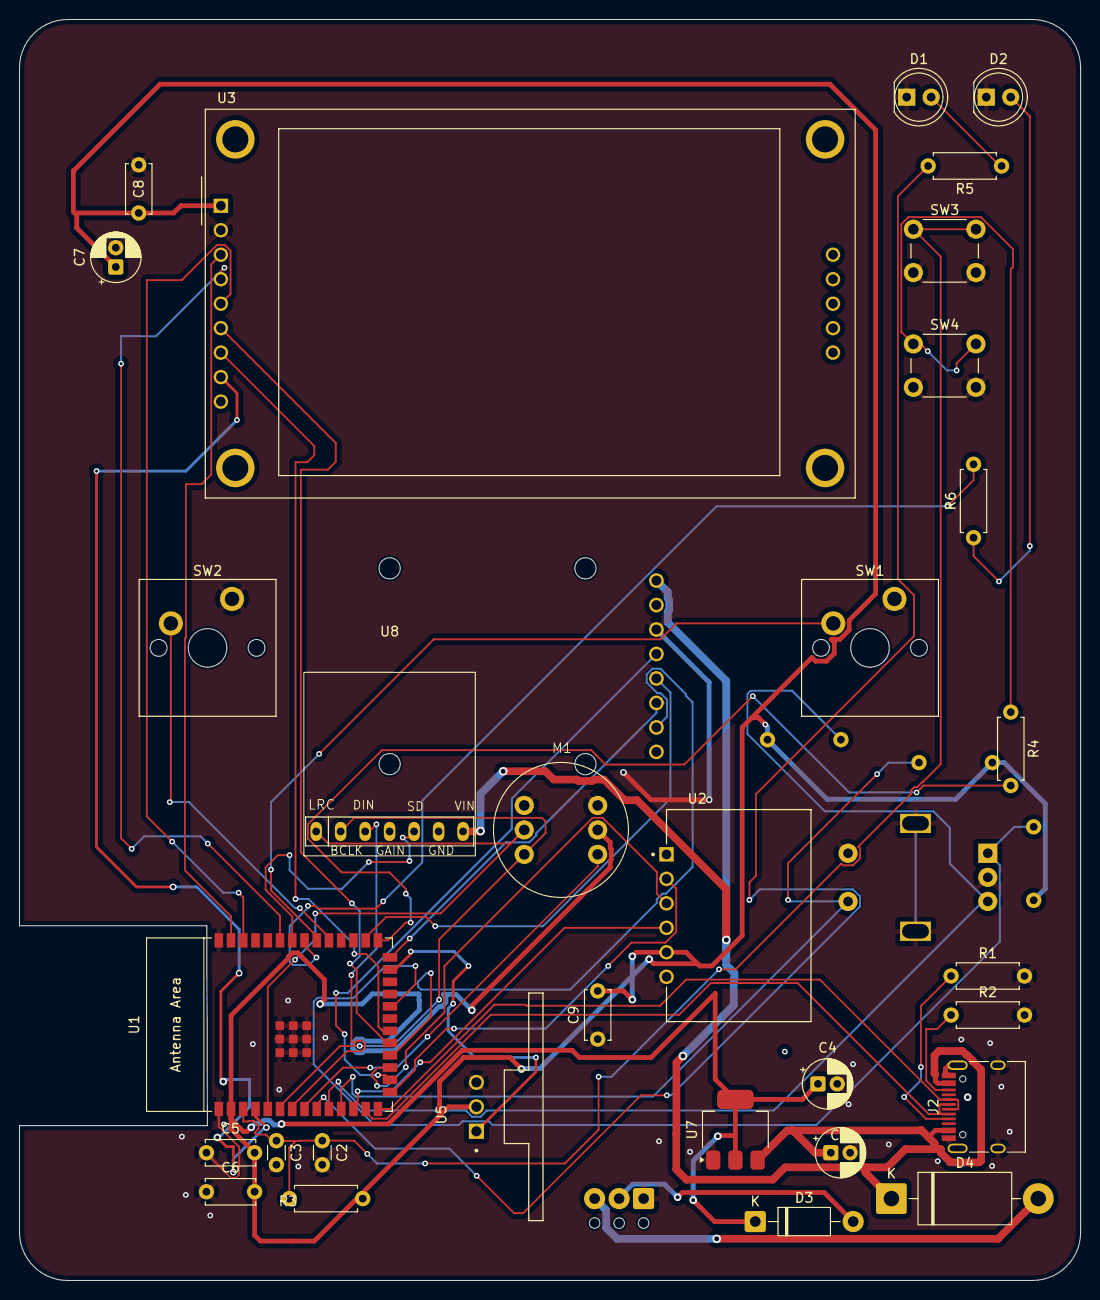
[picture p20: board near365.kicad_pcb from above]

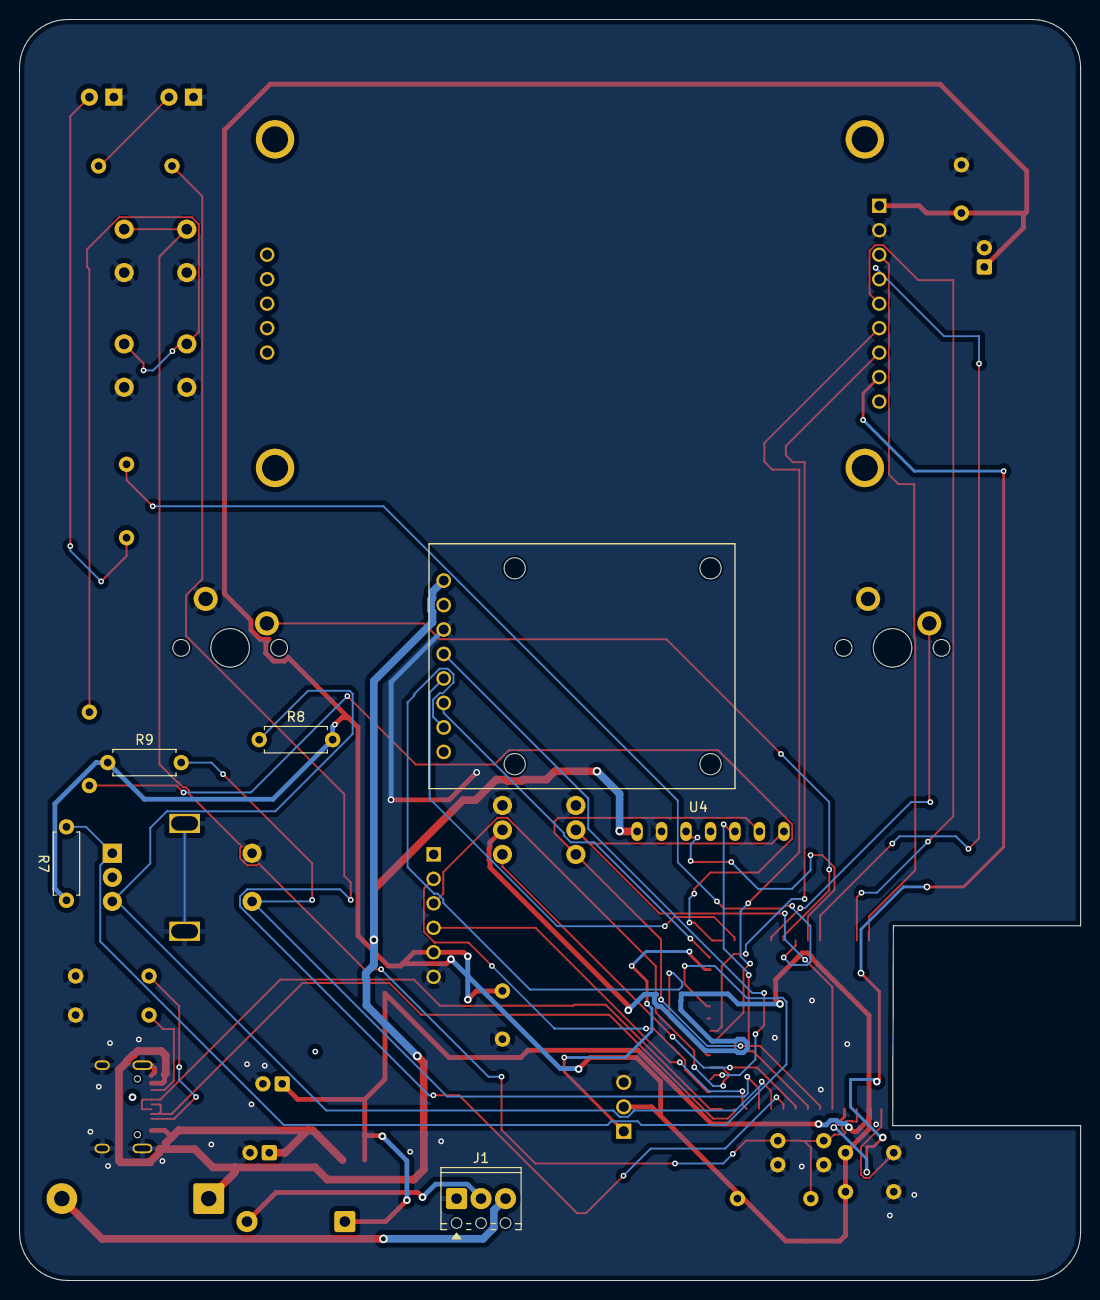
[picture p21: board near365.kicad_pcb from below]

Board: 2 copper layers, 110.1 x 130.8 mm, 37 parts (6 on the bottom side), 40 nets.

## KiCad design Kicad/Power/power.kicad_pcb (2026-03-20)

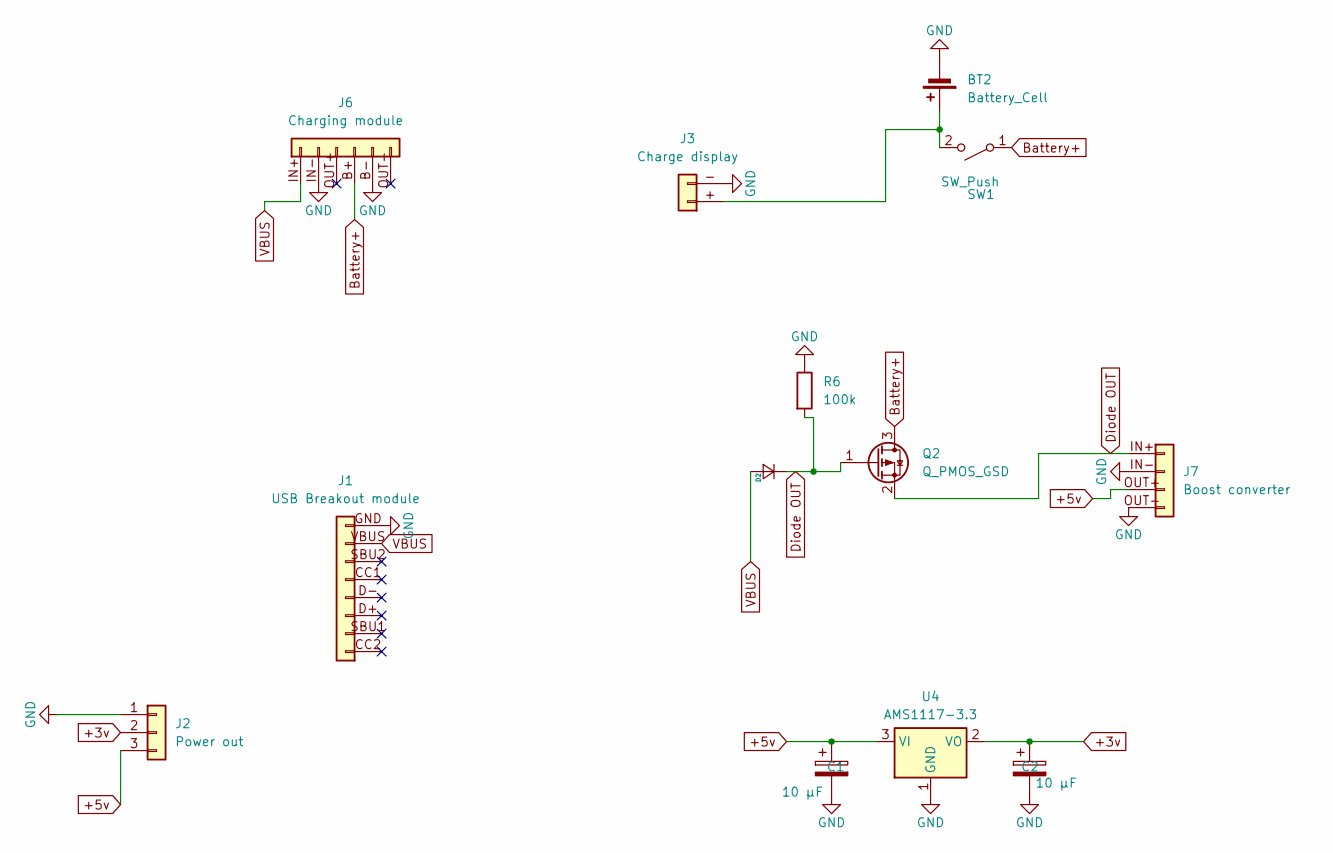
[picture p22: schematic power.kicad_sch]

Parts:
BT2: Battery_Cell; TerminalBlock_Phoenix_PT-1,5-2-3.5-H_1x02_P3.50mm_Horizontal
C1, C2: 10 µF; CP_Radial_Tantal_D4.5mm_P2.50mm
D2: Diode_DO-35
J1: USB Breakout module; Usb_breakout board
J2: Power out; TerminalBlock_Phoenix_MPT-0,5-3-2.54_1x03_P2.54mm_Horizontal
J3: Charge display; charge_display
J6: Charging module; TP4056-Module
J7: Boost converter; Boost_converter_3A
Q2: Q_PMOS_GSD; TO-220-3_Vertical
R6: 100k; R_Axial_DIN0204_L3.6mm_D1.6mm_P5.08mm_Horizontal
SW1: SW_Push; Switch_pads
U4: AMS1117-3.3; SOT-223-3_TabPin2

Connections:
+3v: C2.1, J2.2 (3.3v), U4.2 (VO)
+5v: C1.1, J2.3 (5v), J7.OUT+, U4.3 (VI)
Battery+: J6.B+, Q2.3 (D), SW1.1 (A)
Diode OUT: D2.1 (K), J7.IN+, Q2.1 (G), Q2.2 (S), R6.2
GND: BT2.2 (-), C1.2, C2.2, J1.GND, J2.1 (GND), J3.-, J6.B-, J6.IN-, J7.IN-, J7.OUT-, R6.1, U4.1 (GND)
unnamed: BT2.1 (+), J3.+, SW1.2 (B)
VBUS: D2.2 (A), J1.VBUS, J6.IN+

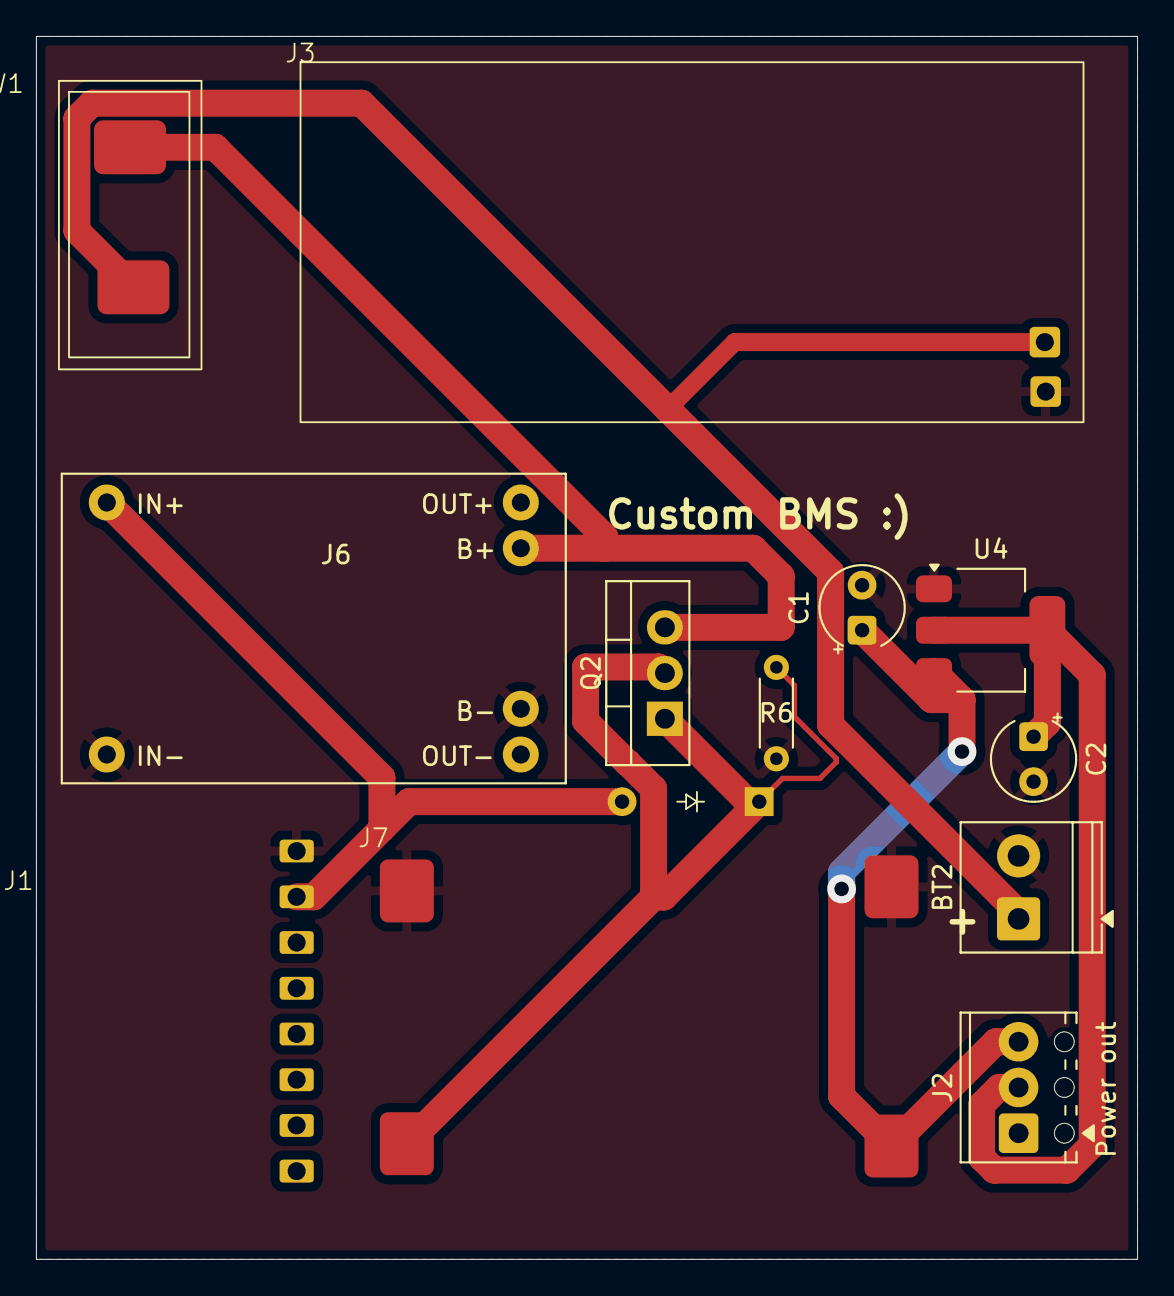
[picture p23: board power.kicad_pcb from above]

Board: 2 copper layers, 61.2 x 67.9 mm, 13 parts (0 on the bottom side), 7 nets.

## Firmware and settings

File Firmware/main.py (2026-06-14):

import lvgl as lv
import time
import random
from setup_test import System_Init, Controls
from pages.router import UIRouter
from machine import Pin
import uasyncio
import context
from actions.play_tone import play_tone
from actions.helper import list_all_songs, connect_to_wifi, get_time, get_today_present


last_states = [False, False, False, False]

hardware_controls = Controls()
print("Initiated inputs")
time.sleep_ms(300)
if not hardware_controls.is_btn1_pressed: #override the wifi connnection logic- for testing
    context.wifi_connected = connect_to_wifi()
    get_time()
    get_today_present()
else:
    print("Did not try to connect to the internet. No time loaded. No present loaded")
    context.wifi_connected = False

system = System_Init()
system.run_all()
time.sleep_ms(100)
print("System init done")

current_states=[context.wifi_connected,system.sd_mounted,bool(context.today_present),bool(context.current_date)]
                    #wifi connected?          sdcard all good?      present loaded?           date loaded?


context.i2s_bus = system.i2s

router = UIRouter()
router.navigate_to("home")

list_all_songs()
print("System successfully initialized")


async def ui_states_refresher(router):
    import context
    current_angle = 0
    while True:
        # Check if a progress bar exists and is active on the current screen
        if hasattr(router, 'active_progress_bar') and router.active_progress_bar:
            try:
                current_val = getattr(context, 'current_progress', 0)
                router.active_progress_bar.set_value(current_val,0)
            except Exception:
                pass
        
        if hasattr(router, "active_spinning_cd") and router.active_spinning_cd:  #rotates the cd if the obj exits
            if context.play.is_set(): #only if the music is playing
                try:
                    current_angle = (current_angle + 120) % 3600
                    router.active_spinning_cd.set_style_transform_rotation(current_angle, 0)
                except Exception:
                    pass
        if hasattr(router, "active_anim_bars") and router.active_anim_bars:
            try:
                for bar in router.active_anim_bars:
                    new_height = random.randint(30, 80)
                    bar.set_height(new_height)
            except Exception:
                pass
            
        if last_states != current_states:  #checks wether states changed for features and updates the UI.
            try:
                old_wifi, old_sd, old_gift, old_clock = last_states
                new_wifi, new_sd, new_gift, new_clock = current_states
                
                if old_wifi != new_wifi:
                    context.home_logo_objs[0].set_style_text_color(lv.color_hex(0x228B22), 0)
                if old_sd != new_sd:
                    context.home_logo_objs[1].set_style_text_color(lv.color_hex(0x228B22),0)
                if old_gift != new_gift:
                    context.home_logo_objs[2].set_style_line_color(lv.color_hex(0x228B22),0)
                if old_clock != new_clock:
                    context.home_logo_objs[3].set_style_line_color(lv.color_hex(0x228B22),0)
            except:
                pass
                
                
        await uasyncio.sleep_ms(800)
        


async def monitor_buttons():
    print("Monitoring buttons states")
    
    debounce_delay = 250
    last_action_time = 0
    
    last_btn1_state = False
    last_btn1_state= False
    last_en_sw_state = False
    
    last_encoder_val = hardware_controls.encoder_value
    
    while True:
        btn1_pressed = hardware_controls.is_btn1_pressed()
        btn2_pressed = hardware_controls.is_btn2_pressed()
        sw_pressed = hardware_controls.is_en_sw_pressed()
        
        encoder_changed = hardware_controls.read_encoder()
        current_time = time.ticks_ms()
        
        if encoder_changed:
            current_val = hardware_controls.encoder_value
            direction = current_val - last_encoder_val
            
            if direction != 0:
                print(f"direction = {current_val} - {last_encoder_val} = {direction}")
                
                if direction > 0:
                    router.process_input(cw=True)
                else:
                    router.process_input(acw=True)
                    
                last_encoder_val = current_val
                

        if time.ticks_diff(current_time, last_action_time) > debounce_delay:
            if btn1_pressed:
                print("Button 1 pressed")
                last_action_time = current_time
                await play_tone()
                router.process_input(btn1=True)
                
            if btn2_pressed:
                print("Button 2 pressed")
                last_action_time = current_time
                await play_tone()
                router.process_input(btn2= True)
            
            if sw_pressed:
                print("En SW pressed")
                last_action_time = current_time
                router.process_input(sw=True)
                
        await uasyncio.sleep_ms(5)
     
     
async def refresh_lvgl():
    while True:
        lv.timer_handler()
        await uasyncio.sleep_ms(10)
        
async def main():
    uasyncio.create_task(monitor_buttons())
    uasyncio.create_task(refresh_lvgl())
    uasyncio.create_task(ui_states_refresher(router))
    
    while True:
        await uasyncio.sleep_ms(1000)
        
    
uasyncio.run(main())
    
            
        
        
        
        

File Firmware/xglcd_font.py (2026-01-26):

"""XGLCD Font Utility."""
from math import ceil, floor


class XglcdFont(object):
    """Font data in X-GLCD format.

    Attributes:
        letters: A bytearray of letters (columns consist of bytes)
        width: Maximum pixel width of font
        height: Pixel height of font
        start_letter: ASCII number of first letter
        height_bytes: How many bytes comprises letter height

    Note:
        Font files can be generated with the free version of MikroElektronika
        GLCD Font Creator:  www.mikroe.com/glcd-font-creator
        The font file must be in X-GLCD 'C' format.
        To save text files from this font creator program in Win7 or higher
        you must use XP compatibility mode or you can just use the clipboard.
    """

    # Dict to translate bitwise values to byte position
    BIT_POS = {1: 0, 2: 2, 4: 4, 8: 6, 16: 8, 32: 10, 64: 12, 128: 14, 256: 16}

    def __init__(self, path, width, height, start_letter=32, letter_count=96):
        """Constructor for X-GLCD Font object.

        Args:
            path (string): Full path of font file
            width (int): Maximum width in pixels of each letter
            height (int): Height in pixels of each letter
            start_letter (int): First ASCII letter.  Default is 32.
            letter_count (int): Total number of letters.  Default is 96.
        """
        self.width = width
        self.height = max(height, 8)
        self.start_letter = start_letter
        self.letter_count = letter_count
        self.bytes_per_letter = (floor(
            (self.height - 1) / 8) + 1) * self.width + 1
        self.__load_xglcd_font(path)

    def __load_xglcd_font(self, path):
        """Load X-GLCD font data from text file.

        Args:
            path (string): Full path of font file.
        """
        bytes_per_letter = self.bytes_per_letter
        # Buffer to hold letter byte values
        self.letters = bytearray(bytes_per_letter * self.letter_count)
        mv = memoryview(self.letters)
        offset = 0
        with open(path, 'r') as f:
            for line in f:
                # Skip lines that do not start with hex values
                line = line.strip()
                if len(line) == 0 or line[0:2] != '0x':
                    continue
                # Remove comments
                comment = line.find('//')
                if comment != -1:
                    line = line[0:comment].strip()
                # Remove trailing commas
                if line.endswith(','):
                    line = line[0:len(line) - 1]
                # Convert hex strings to bytearray and insert in to letters
                mv[offset: offset + bytes_per_letter] = bytearray(
                    int(b, 16) for b in line.split(','))
                offset += bytes_per_letter

    def lit_bits(self, n):
        """Return positions of 1 bits only."""
        while n:
            b = n & (~n+1)
            yield self.BIT_POS[b]
            n ^= b

    def get_letter(self, letter, color, background=0, landscape=False):
        """Convert letter byte data to pixels.

        Args:
            letter (string): Letter to return (must exist within font).
            color (int): RGB565 color value.
            background (int): RGB565 background color (default: black).
            landscape (bool): Orientation (default: False = portrait)
        Returns:
            (bytearray): Pixel data.
            (int, int): Letter width and height.
        """
        # Get index of letter
        letter_ord = ord(letter) - self.start_letter
        # Confirm font contains letter
        if letter_ord >= self.letter_count:
            print('Font does not contain character: ' + letter)
            return b'', 0, 0
        bytes_per_letter = self.bytes_per_letter
        offset = letter_ord * bytes_per_letter
        mv = memoryview(self.letters[offset:offset + bytes_per_letter])

        # Get width of letter (specified by first byte)
        letter_width = mv[0]
        letter_height = self.height
        # Get size in bytes of specified letter
        letter_size = letter_height * letter_width
        # Create buffer (double size to accommodate 16 bit colors)
        if background:
            buf = bytearray(background.to_bytes(2, 'big') * letter_size)
        else:
            buf = bytearray(letter_size * 2)

        msb, lsb = color.to_bytes(2, 'big')

        if landscape:
            # Populate buffer in order for landscape
            pos = (letter_size * 2) - (letter_height * 2)
            lh = letter_height
            # Loop through letter byte data and convert to pixel data
            for b in mv[1:]:
                # Process only colored bits
                for bit in self.lit_bits(b):
                    buf[bit + pos] = msb
                    buf[bit + pos + 1] = lsb
                if lh > 8:
                    # Increment position by double byte
                    pos += 16
                    lh -= 8
                else:
                    # Decrease position to start of previous column
                    pos -= (letter_height * 4) - (lh * 2)
                    lh = letter_height
        else:
            # Populate buffer in order for portrait
            col = 0  # Set column to first column
            bytes_per_letter = ceil(letter_height / 8)
            letter_byte = 0
            # Loop through letter byte data and convert to pixel data
            for b in mv[1:]:
                # Process only colored bits
                segment_size = letter_byte * letter_width * 16
                for bit in self.lit_bits(b):
                    pos = (bit * letter_width) + (col * 2) + segment_size
                    buf[pos] = msb
                    pos = (bit * letter_width) + (col * 2) + 1 + segment_size
                    buf[pos] = lsb
                letter_byte += 1
                if letter_byte + 1 > bytes_per_letter:
                    col += 1
                    letter_byte = 0

        return buf, letter_width, letter_height

    def measure_text(self, text, spacing=1):
        """Measure length of text string in pixels.

        Args:
            text (string): Text string to measure
            spacing (optional int): Pixel spacing between letters.  Default: 1.
        Returns:
            int: length of text
        """
        length = 0
        for letter in text:
            # Get index of letter
            letter_ord = ord(letter) - self.start_letter
            offset = letter_ord * self.bytes_per_letter
            # Add length of letter and spacing
            length += self.letters[offset] + spacing
        return length

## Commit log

2026-01-26 Full project (v1) commit
    [near365.csv, near365.kicad_pcb, near365.kicad_sch]
2026-03-06 New changes- new case redesign
    [Power.kicad_pcb, Power.kicad_sch, backplate.stl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]
2026-03-09 Added BOM info
    [Main Board.csv, Power-kicad.csv, Power.csv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]
2026-03-20 Updated power, made changes to 3d front plate, added pull down r to encoder
    [Power.kicad_pcb, Power.kicad_sch, bom.csv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]
2026-06-02 LVGL and display with ui pages switching on button presses. Speaker setup
    [near365.kicad_pcb]
2026-06-12 Music selection to play any song and encoder input fix
    [context.py, main.py, play_from_sd.py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]
2026-06-13 Added song page and logic. Bug fixes
    [context.py, main.py, play_from_sd.py]
2026-06-13 Song page logic with prev and next. UI for song page. Ui fixes. Bug fixes
    [context.py, main.py, play_from_sd.py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]
2026-06-14 Home page completion and bug fixes
    [context.py, helper.py, main.py]
